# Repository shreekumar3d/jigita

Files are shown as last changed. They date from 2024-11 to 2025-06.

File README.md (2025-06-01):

Jigit

# Jig It !

Ease PCB assembly with 3D printed jigs. Achieve perfectly aligned connectors, with no special motor skills!

JigIt is licensed under the AGPL 3.0 License. If you work with electronics, it can
help you save time, material and money. Should you find value in this tool, the
author implores you to take on the moral obligation of abiding by the
"Equal Opportunity" manifesto. Details of what "equal opportunity" means and your
obligations are in [this page](EQUAL-OPPORTUNITY.md). Please take a moment to read
it before you start using the software.

Starting with a PCB design, JigIt achieves this workflow:

 1. Create a 3D printable jig design from a PCB design.
 2. Print jig.
 3. Mount components and PCB on jig. If you notice tolerance issues, tweak parameters, goto step 1.
 4. Solder away for perfect results... every time !

Jig Usage

Do checkout [this project's hackaday page](https://hackaday.io/project/198409-pcb-assembly-jig-generator)
for stories and updates.

## Demos

There are many ways to use JigIt. Checkout the [demos directory](demos) for details; here are some examples:

[Raspberry Pi Pico/Pico 2](demo/01-rpi-pico-soldering-jig/README.md)

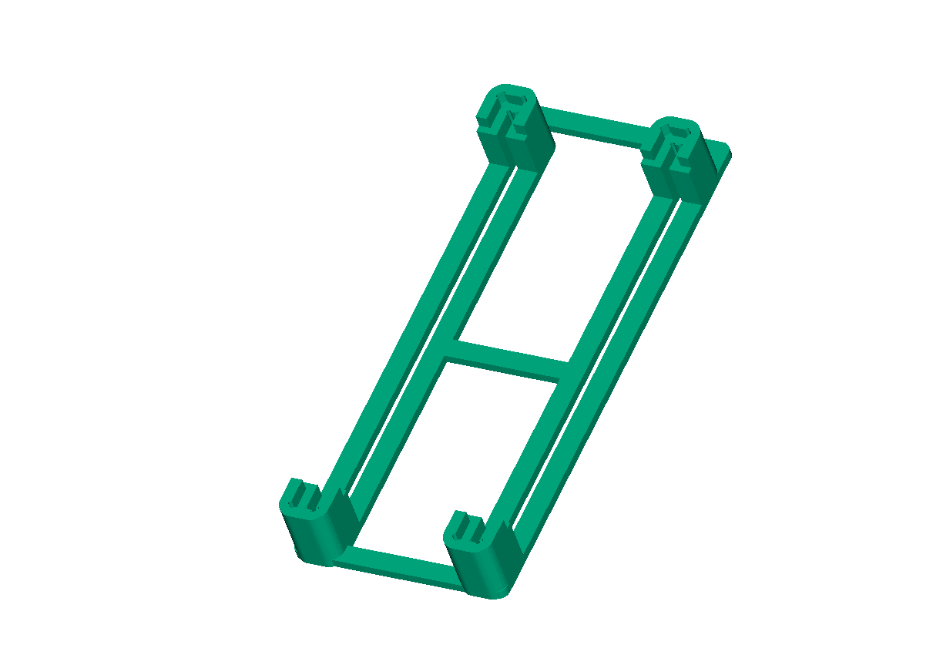
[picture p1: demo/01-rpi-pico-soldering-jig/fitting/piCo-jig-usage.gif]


[Pico Glitcher Board](demo/02-pico-glitcher/README.md)

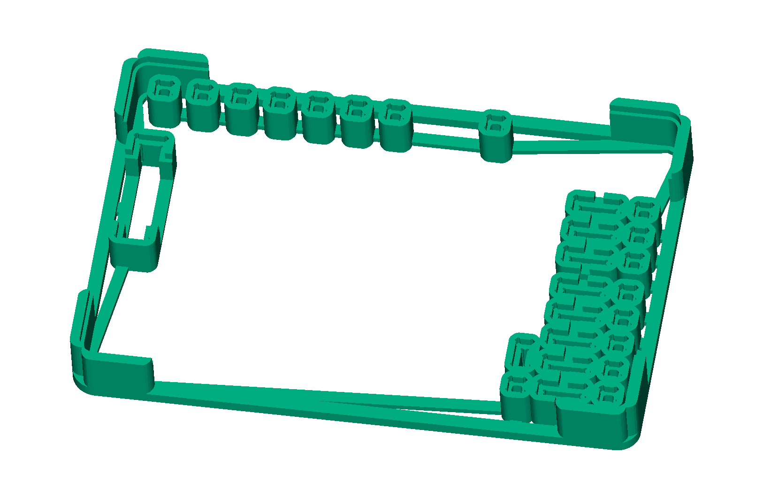
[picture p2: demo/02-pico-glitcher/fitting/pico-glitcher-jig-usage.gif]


JigIt is generic. Have a crazy board like this ProtoConn to solder ?



See [ProtoCon demo](demo/06-lots-of-connectors/README.md) for the details; the jig would look and work like this:

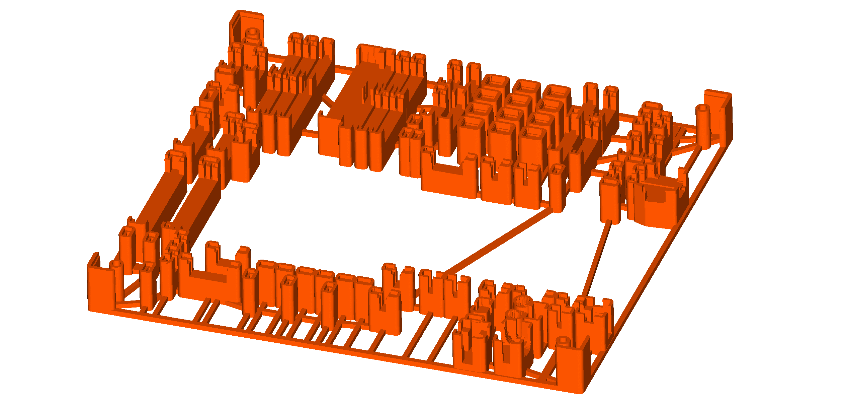
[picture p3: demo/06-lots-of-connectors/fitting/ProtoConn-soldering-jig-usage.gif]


[Gridfinity Containers for Electronics](demo/05-gridfinity/README.md)

It's not just for soldering - make Gridfinity containers for all your electronic components in a snap:

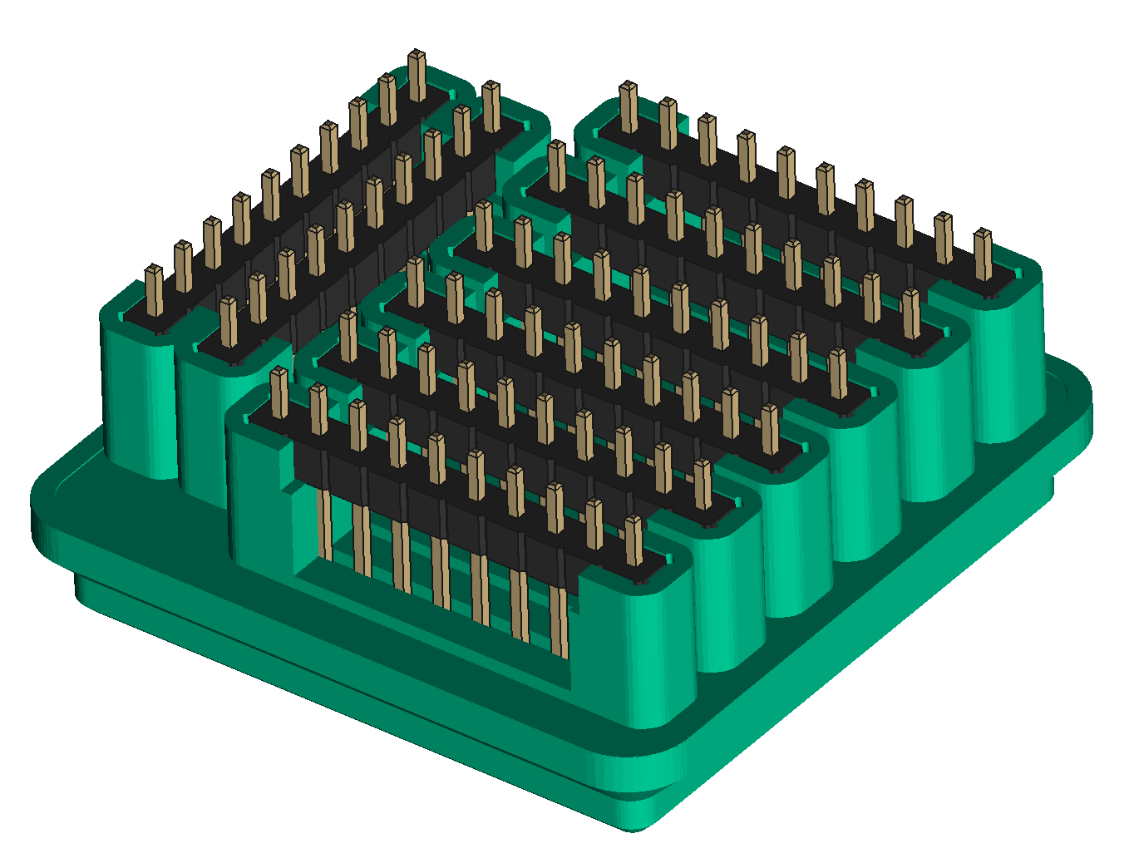
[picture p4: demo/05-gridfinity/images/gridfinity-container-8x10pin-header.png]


It can be used for more than electronics too, with just a bit more work.... Here is an example of a gridfinity container holding three allen keys - M2, M3 and M4:

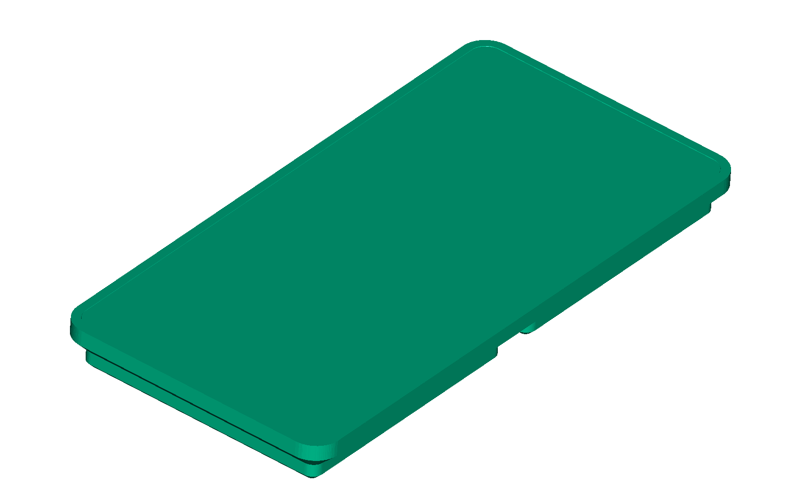
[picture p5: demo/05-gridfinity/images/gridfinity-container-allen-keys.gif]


## Getting Started

See the [Getting Started page](doc/GETTING-STARTED.md).

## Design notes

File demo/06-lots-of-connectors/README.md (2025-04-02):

# ProtoConn

[ProtoConn](https://github.com/Pakequis/ProtoConn) is a prototyping board with
connectors for electronic testing and development. It has an seriously impressive
array of connectors:



Soldering all those components is quite a task.  The large board size of 200x195 mm
calls for some method to hold everything in place.

Here is a soldering jig that solves the problem, created with JigIt:

ProtoConn meets JigIt

This isn't tested yet, but apart from a USB connector that can't be soldered (it's
probably set to SMD) there is a good chance it would work.

To generate the jig, first clone the ProtoConn repository:

    git clone https://github.com/Pakequis/ProtoConn

(tested against commit ffd7c437a8)

The jig was generated using:

    jigit \
      -i ProtoConn/Hardware/ProtoConn.kicad_pcb \
      -c ProtoConn.toml \
      -o jigs/ProtoConn-soldering-jig.3mf

The pre-generated jig is at [jigs/ProtoConn-soldering-jig.3mf](jigs/ProtoConn-soldering-jig.3mf).
You can also take a closer look at the fitting of the jig and the components
by using FreeCAD with this file:
[fitting/ProtoConn-soldering-jig-fitting.FCStd](fitting/ProtoConn-soldering-jig-fitting.FCStd)

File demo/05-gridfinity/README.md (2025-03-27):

# Gridfinity Containers

Jigit can be used to build electronics storage containers for
[Gridfinity](https://gridfinity.xyz/), the popular open source grid storage system.
The cool thing about is that almost the entire workflow happens in your favourite
electronic design software, [KiCAD](https://www.kicad.org/).  KiCAD comes with a
huge library of parts. For components you use, you probably already have your
footprints and symbols defined. With Jigit you can build storage containers for
any of them, in any combination and more.

As an example, here is a gridfinity container that can hold eight 10 pin headers:



Gridfinity works on a grid of 42 mm x 42 mm for the baseplate. A single gridfinity
container is a rounded 41.5 mm square. See the
[specification](https://gridfinity.xyz/specification/) for details.

Jigs generated by jigit may be thought of as a storage container for a set of
electronic components.  The gridfinity container shape can be modelled as a PCB
shape.  The components you need to "store" in the container are placed on the
PCB as desired. Here is one sample layout for a gridfinity container that can
hold ten 1x10 pin standard(2.54mm pitch) headers:

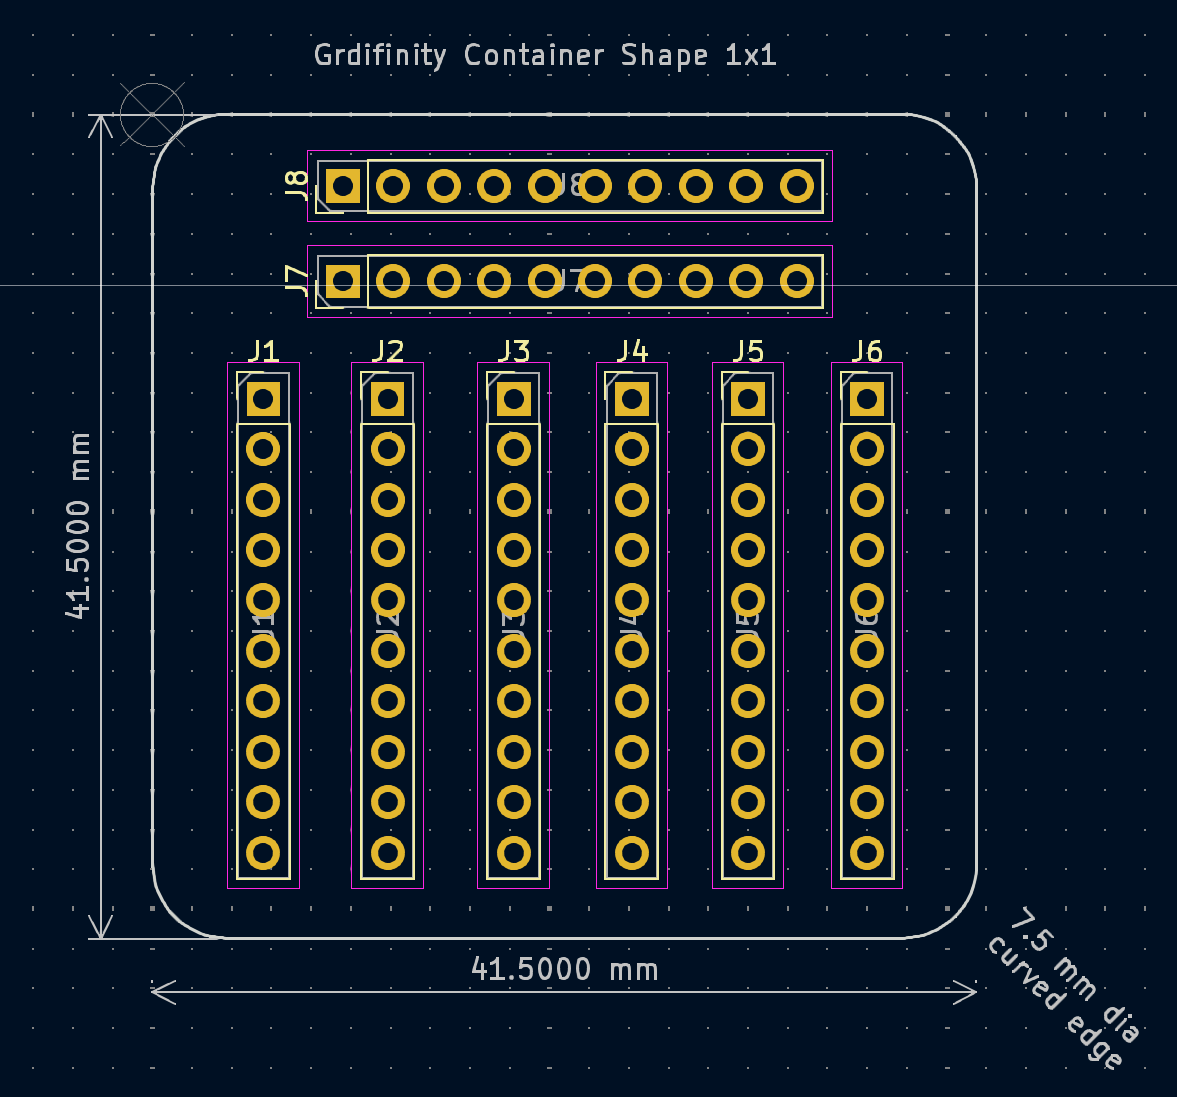
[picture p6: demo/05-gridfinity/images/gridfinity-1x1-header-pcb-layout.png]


Generating the Jig is a simple matter as usual:

    jigit \
      -i gridfinity-1x1/gridfinity-1x1.kicad_pcb \
      -c gridfinity.toml \
      -o jigs/gridfinity-1x1.3mf

Do refer to the settings in the configuration file
[gridfinity.toml](gridfinity.toml).

The resultant jig lacks the gridfinity base.  This needs to be merged in
to create a complete gridfinity container.

[Gridfinity Generator](https://gridfinity.perplexinglabs.com/pr/gridfinity-rebuilt/0/0)
provides a convenient way to generate gridfinity compatible base designs.
Setting height to 1 mm, and disabling the "stackiing lip" provides a convenient
building block with an almost flat top.

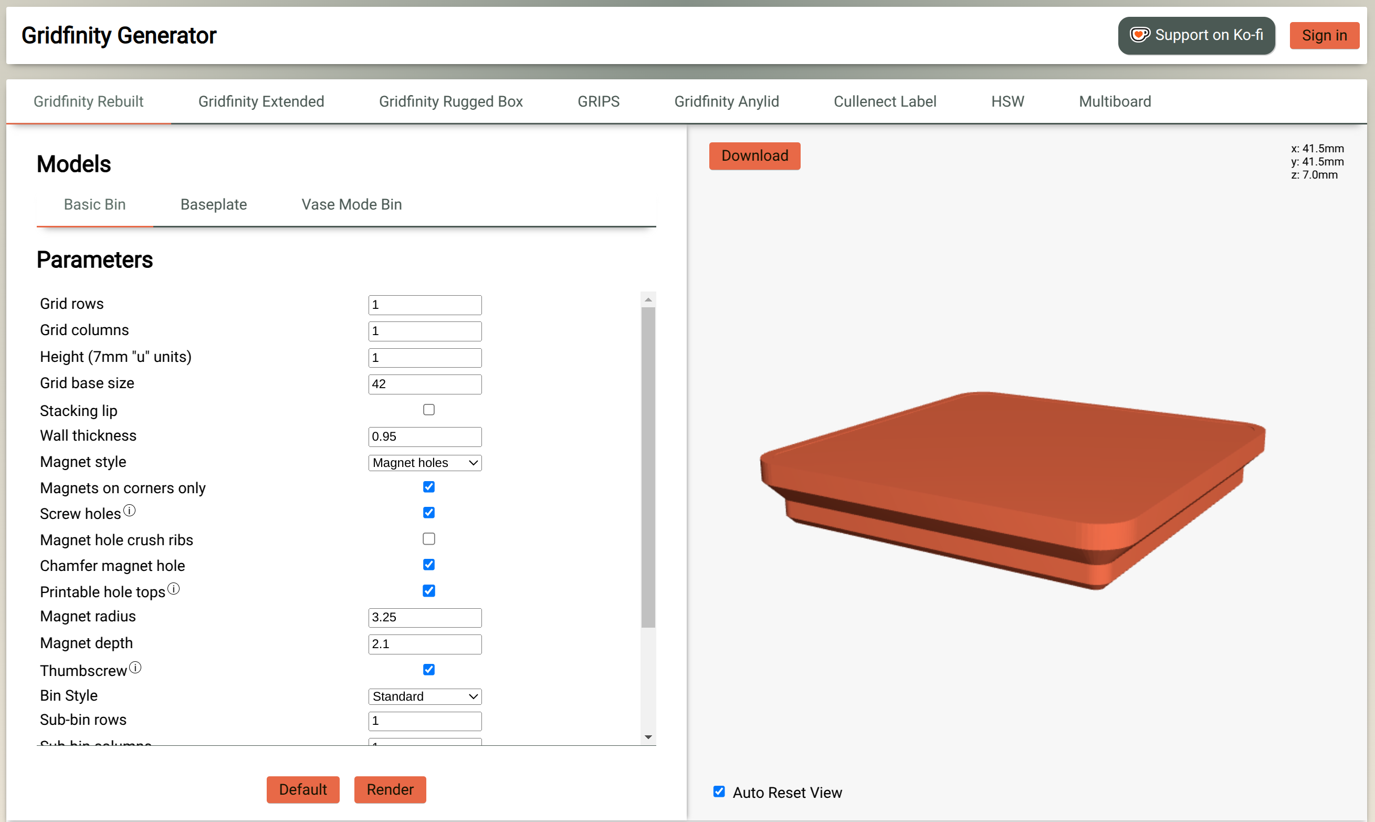
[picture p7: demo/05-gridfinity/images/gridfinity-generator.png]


I have download and saved this file as
[base/base-gridfinity-1x1.stl](base/base-gridfinity-1x1.stl).

To merge the models, let's fire up the slicer (Prusa Slicer in my case).
We'll follow a workflow following the steps in
[this article](https://help.prusa3d.com/article/how-to-lift-object-from-the-print-bed_245192).
First we'll load the base model.  Then we'll right click on the model,
choose "Add Part...", then "Load". Then we'll select the generated jig file.
The jig will get added at unexpected positions. You'll need to match the
position (X, Y) of the jig to the base model. Then change the Z value to
make the generated jig "sit" on the base container. With the right values,
you'll end up with this:

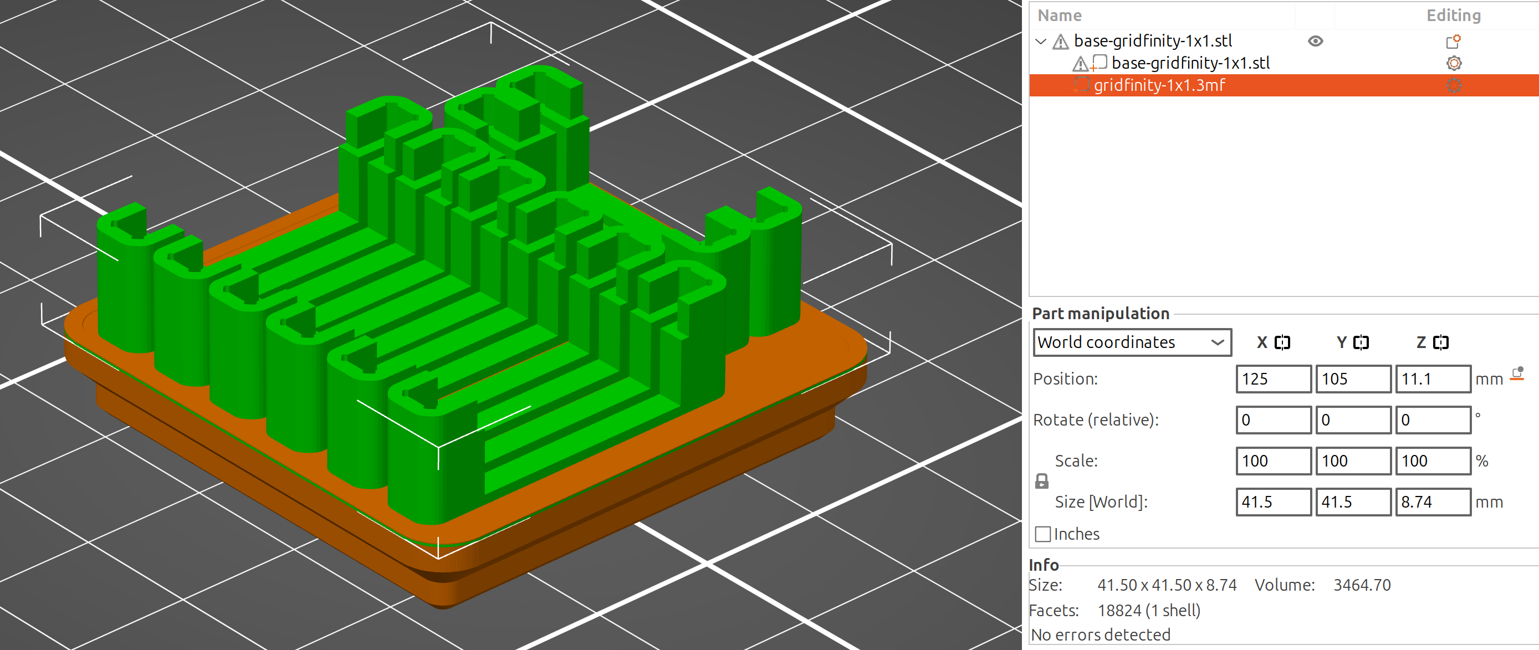
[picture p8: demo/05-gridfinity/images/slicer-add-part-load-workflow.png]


You can now print the resulting file, or save it, say as
[containers/gridfinity-container-8x10pin-header.stl](containers/gridfinity-container-8x10pin-header.stl).
There you have it - gridfinity containers for your own components are just
a few minutes away.

I use FreeCAD with the
[KiCAD StepUp mod](https://www.kicad.org/external-tools/stepup/) workbench for
drawing the PCB outlines to the correct dimension and shape. The container
shapes are in
[gridfinity-container-shapes.FCStd](gridfinity-container-shapes.FCStd)

# Beyond Electronic Components...

KiCAD allows you to load mutiple 3D models into a footprint. These models are
thus not restricted to being electronics components... they can be anything
else too!  After arranging these models in your desired arrangement, you can
then use Jigit to generate generic holders.

Using KiCAD this way is somewhat unusual... but possible! JigIt doesn't have
a UI (yet!) so KiCAD is basically a round-about way to place objects in 3D,
and then have JigIt do its work.

Here is an example of a gridfinity container holding three allen keys -
 M2, M3 and M4:



The relevant files are:

  * KiCAD Design file:
    [allen-keys/allen-keys.kicad_pcb](allen-keys/allen-keys.kicad_pcb)
  * Allen Key 3D models were generated using the Fasteners workbench in FreeCAD,
    and are in [allen-keys/3dmodels](allen-keys/3dmodels)
  * Configuration file to generate jig : [allen-keys.toml](allen-keys.toml)
  * Generated Jig : [jigs/allen-keys.3mf](jigs/allen-keys.3mf)
  * Merged Gridfinity container : [containers/gridfinity-container-allen-keys.stl](containers/gridfinity-container-allen-keys.stl)
  * Gridfinity container base: [base/base-gridfinity-2x1.stl](base/base-gridfinity-2x1.stl)

The workflow is same as earlier, except 3D models of allen keys are assigned
to KiCAD footprints. 3D models also positioned on the same side as the PCB.
If you lookup the design you'll find that they are positioned that the allen
keys are at the same level, despite their differing sizes. Jigit would
ordinarily ignore those; force_mount" is set to true in the config file to
include those.

The jig was generated (as you might expect) using this command:

    jigit \
      -i allen-keys/allen-keys.kicad_pcb \
      -c allen-keys.toml \
      -o jigs/allen-keys.3mf

This feature may be used in many ways. Shipping a kit of components and some
extra hardware ? Use it to add some polish to your kit!

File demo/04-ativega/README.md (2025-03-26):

# AtiVEGA

[AtiVEGA](https://github.com/shreekumar3d/thejas32-testbed) is the board that
lead to the creation of this project.  AtiVEGA is a project to study, understand
and document the THEJAS32 microcontroller.

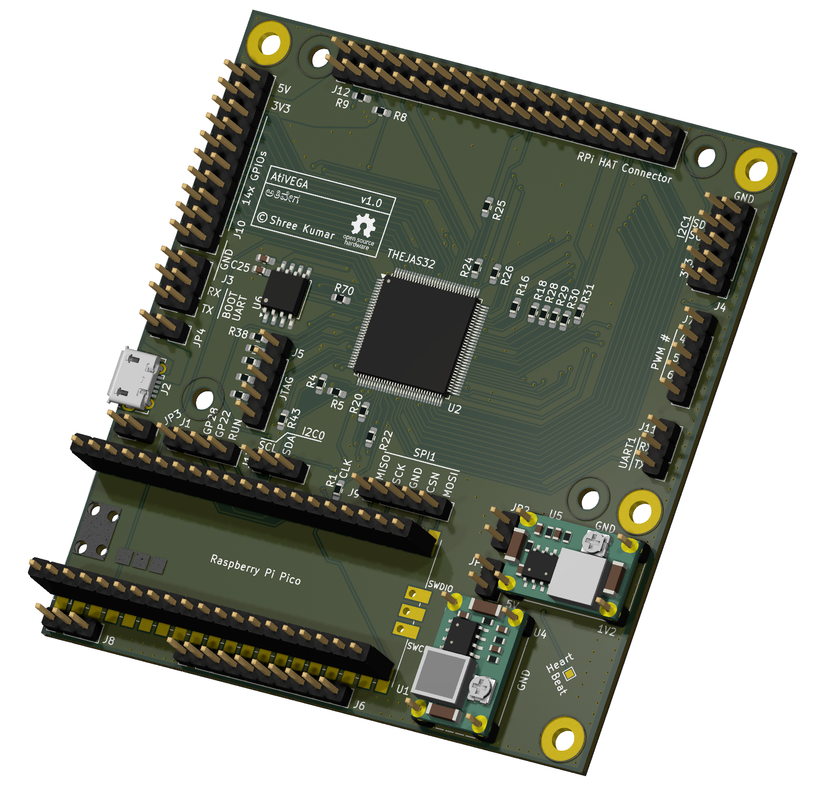
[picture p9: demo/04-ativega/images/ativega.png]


## Story

Many FOSS projects are born out of personal pain points. For Jigita, AtiVEGA
was that pain. Or rather, the pain of soldering the headers on the board.
The board has 26 separate headers:

  * 1 2x20 pin header
  * 1 2x10 pin header
  * 2 1x20 pin sockets
  * 1 1x10 pin header
  * 1 2x5 pin header
  * 1 2x3 pin header
  * 3 1x5 pin headers
  * 1 1x4 pin header
  * 3 1x3 pin headers
  * 4 1x2 pin headers
  * 8 single pin headers!

The single row headers were downright frustrating to solder. I was not happy
with the results as the headers were not perfectly straight most of the times.
Soldering the single pin headers was agony. Not that all that didn't work. It
did. It's just that the effort was too much, and that the results were ugly.

A better method was needed. That's when I decided to build a 3D printed
jig for this. The various shell algorithms evolved with me iteratively testing
jigs with the board. I was always trying to get the fitting right, never once
bothering to solder the board during development. I also realized that this
tool would be generically useful, so I built it as a command line tool with
input from a config file to tweak various things down to a component level.

## Make the Jig!

First, get the design files:

    git clone https://github.com/shreekumar3d/thejas32-testbed

The jig I use now for assembling the board is generated using jigit, using the
following command:

    jigit \
      -i thejas32-testbed/hw/thejas32-testbed.kicad_pcb \
      -c ativega.toml \
      -o jigs/ativega-jig.3mf

The resulting jig [jigs/ativega-jig.3mf](jigs/ativega-jig.3mf) has a shell (holder) for
every component. The PCB can sit in the groove at the four corners. It also has
a provision to insert M3 bolts at the locations of the mounting holes. Additionally,
an M3 bolt may be used near the corner of the PCB that lacks a mounting hole in
the board design.

The workflow with the jig is:

 1. Start with the jig
 2. Insert M3 bolts, lay flat on a table (optional)
 3. Insert headers and USB connector (optional)
 4. Insert the PCB, using the M3 bolts as guides
 5. Hold the PCB in place using M3 nuts (optional)
 6. Check fit and solder!

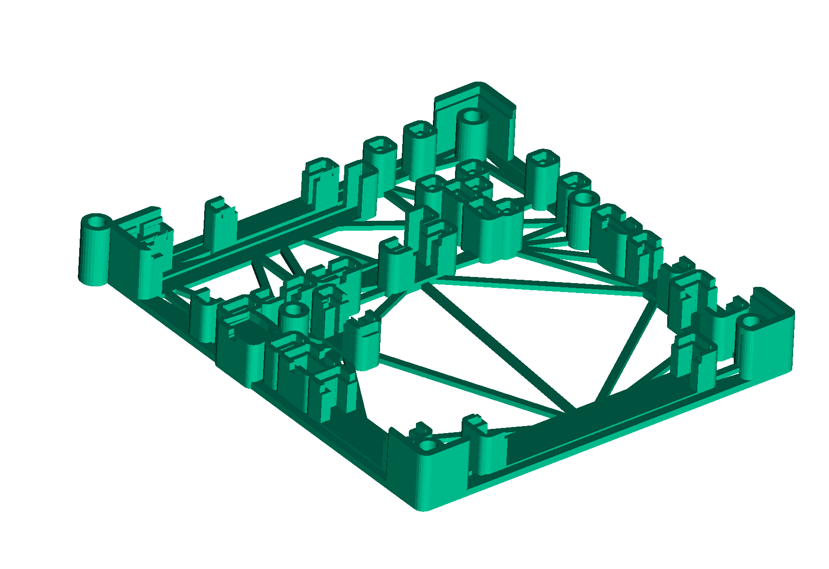
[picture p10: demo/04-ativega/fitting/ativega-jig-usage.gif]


You may check the fitting of these, using FreeCAD by opening this file:
[fitting/ativega-jig-fitting.FCStd](fitting/ativega-jig-fitting.FCStd).

## OpenSCAD Customizer

Changing a configuration file and running the tool to tweak parameters is fine,
but a UI is nicer for tuning. OpenSCAD provides a simple customizer
UI. Jigit has interdependent configuration parameters; not all combinations are
valid. Such things can't be coded into the UI. This makes the customizer less
than ideal, but I figured out I would have to make things work with whatever
limitations it posed. The UI has some extra text which serves as warnings, but
that's pretty much it.

Generating the openscad file is a simple matter of changing the filename
extension of the output:

    jigit \
      -i thejas32-testbed/hw/thejas32-testbed.kicad_pcb \
      -c ativega.toml \
      -o jigs/ativega-jig.scad

Now you may open [jigs/ativega-jig.scad](jigs/ativega-jig.scad) using OpenSCAD. For
**_fast_** mesh generation performance, use a development version and turn on the
usage of Manifold (under Preferences > Advanced > 3D Rendering > Backend).

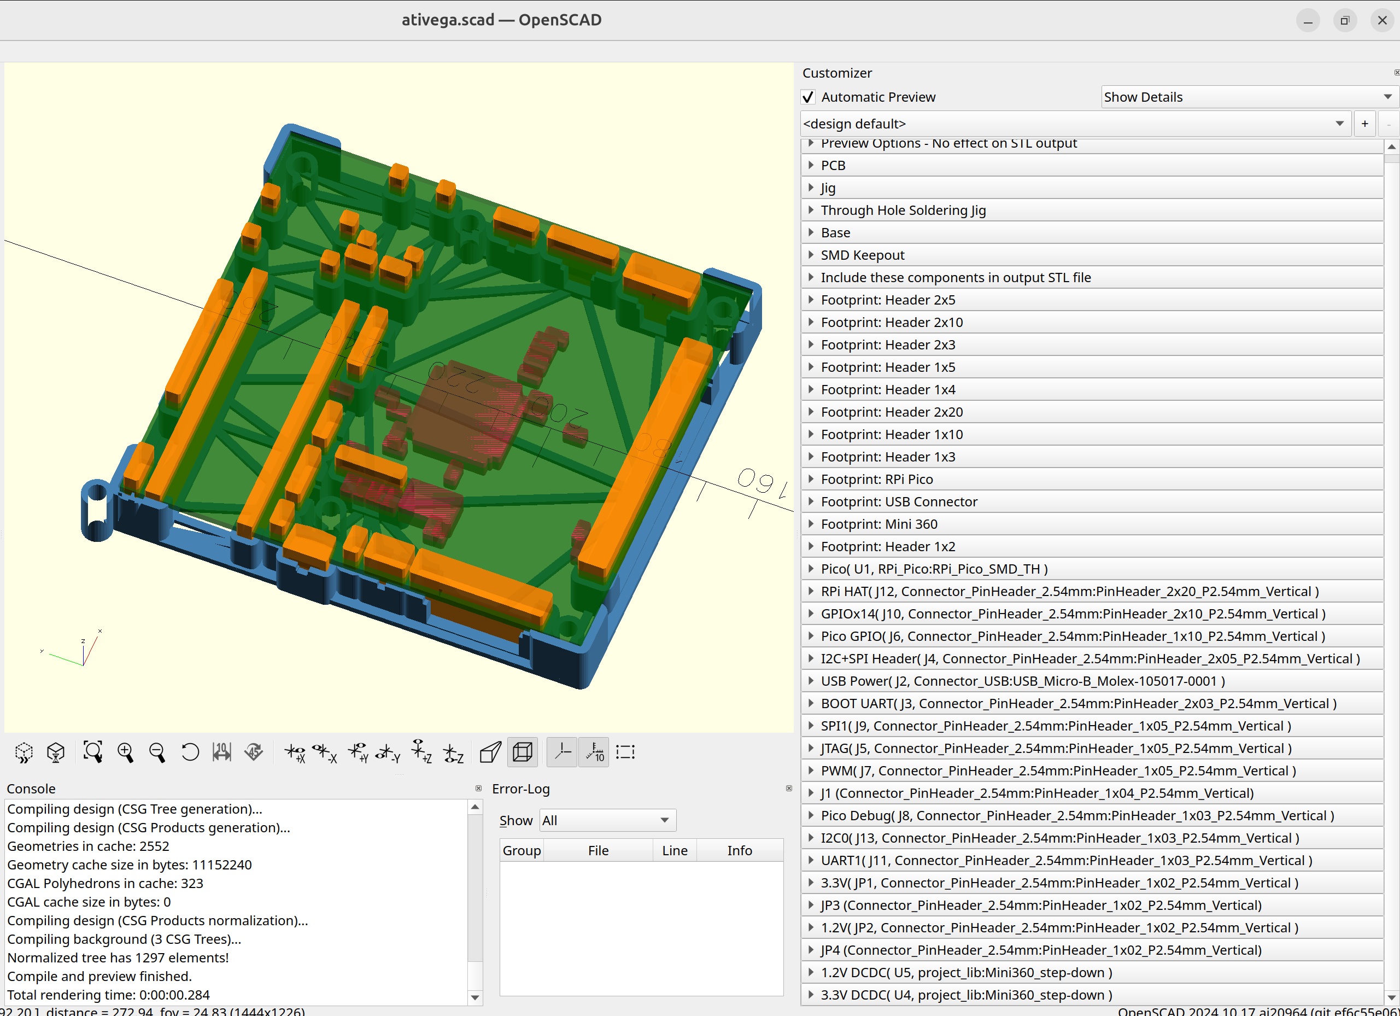
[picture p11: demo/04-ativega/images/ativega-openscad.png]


The panel on the right has helpful labels identifying components.

# Advanced Usage

## Two part jig

Jigit can create a "two part" jig as well. This makes even more of the internal
structure visible, and may take less time/material, depending on the mode
(not the case for AtiVEGA):

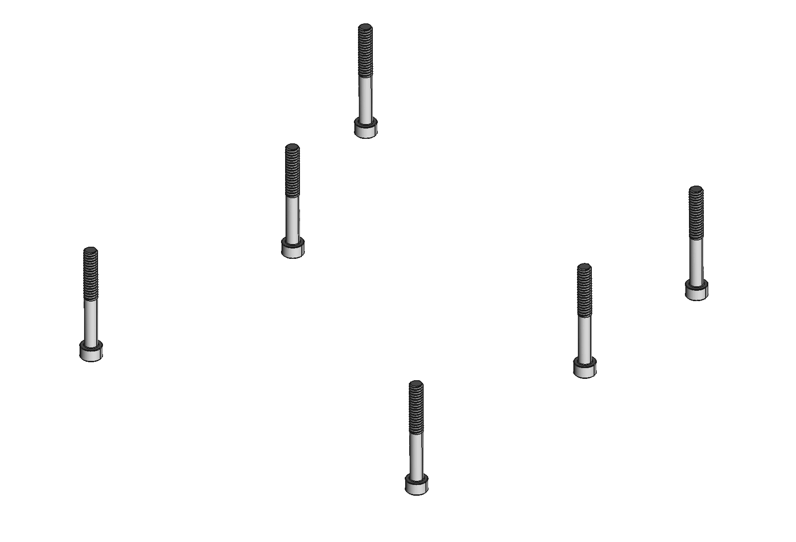
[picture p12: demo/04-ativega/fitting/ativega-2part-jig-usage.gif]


This is generated by using the following command with jigit:

    jigit \
      -i thejas32-testbed/hw/thejas32-testbed.kicad_pcb \
      -c ativega-2part-jig.toml \
      -o jigs/ativega-2part-jig.3mf

The resulting jig [jigs/ativega-2part-jig.3mf](jigs/ativega-2part-jig.3mf) has two
parts separated by a small gap.  This gap isn't visible easily.  However, you can
use an option in your slicer to split this into two parts. In Prusa Slicer, this
option is called "split to objects". After that, choose "arrange objects".
Once done, the model will look as below, in the slicer:

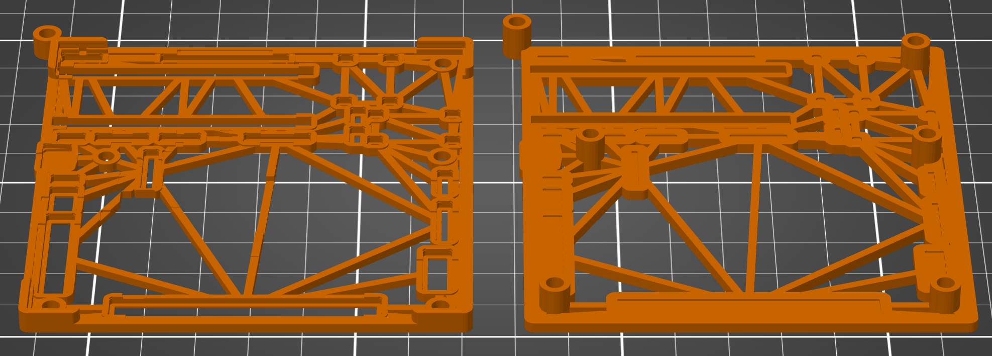
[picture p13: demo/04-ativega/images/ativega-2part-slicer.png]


The model can now be printed.

The 2 part jig may feel somewhat flimsy compared to a single part jig.  This may
come in useful for projects that have taller jigs. It also sparks ideas about
other ways of building jigs - e.g. using laser cut thin acrylic or steel sheets,
or even cardboard.

The 2 part jig should be considered experimental. Tou should ideally cross-check
the generated jig in the slicer prior to printing.

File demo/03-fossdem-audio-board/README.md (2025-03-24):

# FOSSDEM Audio Board

This illustrative example showcases jigit handling components of various heights.

[FOSSDEM](https://fosdem.org/2025/) conference uses a
[dedicated "videobox"](https://blog.brixit.nl/after-fosdem-videobox-updates/)
to record and live-stream their videos. Their "box" has various internal boards,
including a
[digital audio mixer board](https://blog.brixit.nl/digital-audio-mixer-pt-2/).

The audio board has a few XLR audio connectors (two different types of connectors),
a berg header, and a couple of audio jacks. The board looks roughly like this in
3D:

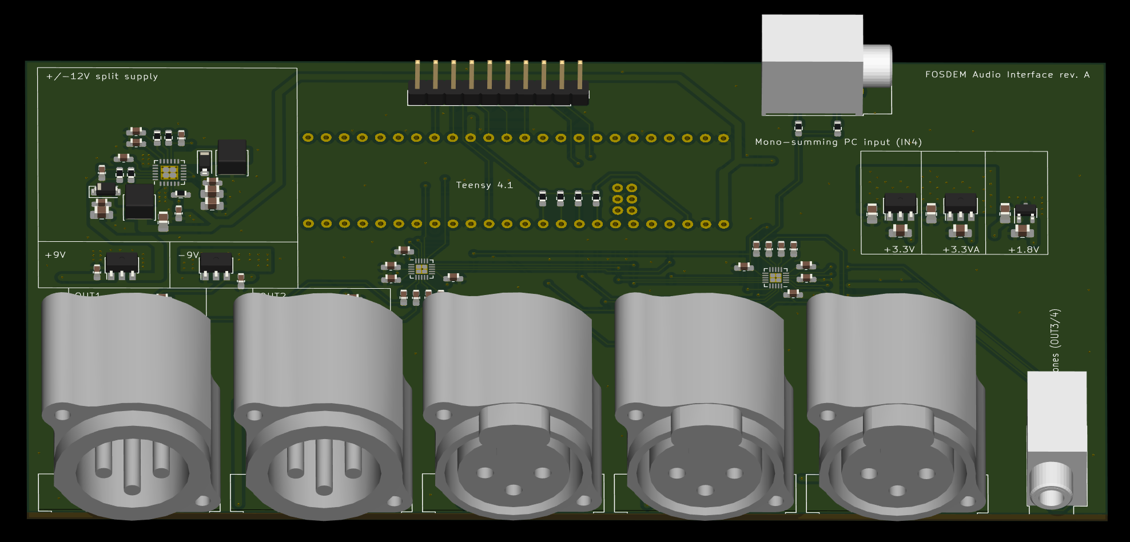
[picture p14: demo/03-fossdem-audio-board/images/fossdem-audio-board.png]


Jigit can be used to create a soldering jig for this board. We first need to get
the design files:

    git clone https://git.sr.ht/~martijnbraam/mixolydian-4x4

(tested with git commit a2705c04)

Next, use the following command:

    jigit \
      -i mixolydian-4x4/mixolydian-4x4.kicad_pcb \
      -c mixolydian-4x4.toml \
      -o jigs/mixolydian-4x4-soldering-jig.3mf

Here's how the generated jig [mixolydian-4x4-soldering-jig.3mf](jigs/mixolydian-4x4-soldering-jig.3mf)
looks and works:

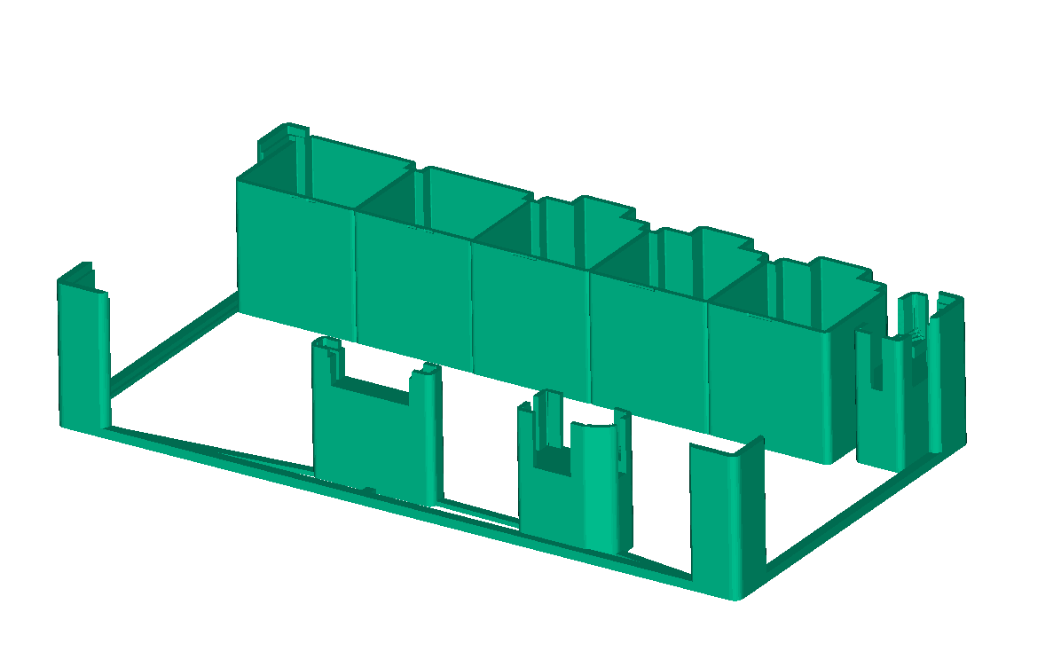
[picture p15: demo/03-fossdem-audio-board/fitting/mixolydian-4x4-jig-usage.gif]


The jig sits on a groove at the board edges. The PCB sits on it. Note that
different types of holding structures are generated for the two different types
of XLR connectors. Also note that the holding structures are connected to the
main structure, ensuring a printable single piece model.

The board also uses a Teensy 4.1. However, the 3D models for the teensy footprint
are not included in the PCB design. Thus, jigit doesn't generate structures to hold
the berg header used to mount the Teensy. Same is the case of the ethernet breakout
pins of the Teensy.

The jig generated jig here hasn't been tested with a real board. It should work,
though. You may also verify the fitting by opening this file in FreeCAD:
[fitting/mixolydian-4x4-jig-fitting.FCStd](fitting/mixolydian-4x4-jig-fitting.FCStd)

This is a medium size PCB - 152 mm x 80 mm. The jig would take an estimated 43 grams of
material, and print in 4 hrs 30 min at 0.2mm layer height in my printer (Prusa i3
MK2 with 0.4 mm nozzle).

A common way of creating soldering jigs involves manually creating cavities inside
a solid. With a change of options, Jigit can generate such jigs as well..! E.g.

    jigit \
      -i mixolydian-4x4/mixolydian-4x4.kicad_pcb \
      -c mixolydian-4x4-solid.toml \
      -o jigs/mixolydian-4x4-soldering-jig-solid.3mf

That gives us [mixolydian-4x4-soldering-jig-solid.3mf](jigs/mixolydian-4x4-soldering-jig-solid.3mf),
which looks like this:

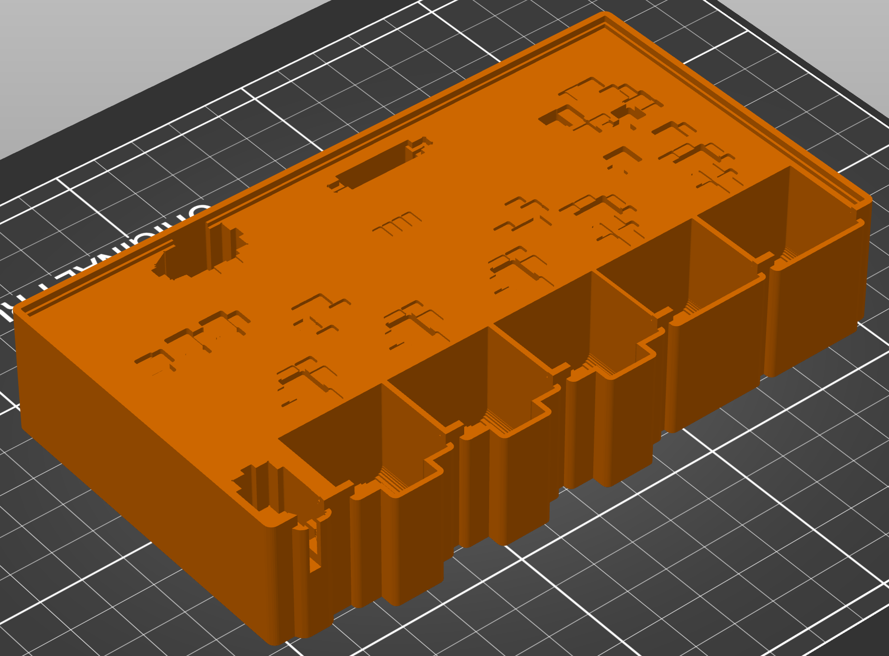
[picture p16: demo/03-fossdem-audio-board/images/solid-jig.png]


This model has cavities for SMD components with ample clearance.  A partially
assembled board (e.g. with SMD components) can thus be used with this jig.

Printing this model even with 5% infill would need 80 grams of material (2x) and
6 hrs+ on my printer with 0.2mm layer height. We save close to 50% on time and
material by generating component holders where needed.

Finally, sparse holders makes it easy to examine and verify (and if necessary tune)
the fit.

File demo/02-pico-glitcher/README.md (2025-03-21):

# Pico Glitcher

[fault-injection-library](https://github.com/MKesenheimer/fault-injection-library)
is an interesting project. It provides a python library to perform fault injection
attacks on microcontrollers.  Also includes PicoGlitcher - hardware based on a RPi
Pico for fault injection. [PicoGlitcher v1](https://www.tindie.com/products/faulty-hardware/picoglitcher-v1-pcb-only/)
and [PicoGlitcher v2](https://www.tindie.com/products/faulty-hardware/picoglitcher-v2/)
are both available.

The v1 variant has many headers and a 2 SMA connectors. This board caught my eye as
a good community board to test with. I was able to generate a jig for this. (The
project has some jigs to assist soldering too, likely designed manually)

First, get the design files:

    git clone https://github.com/MKesenheimer/fault-injection-library.git

(tested with git commit 0122cd1d)

Next, generate the jig using jigit:

    jigit \
      -i fault-injection-library/schematics/kicad/pico-glitcher-v1/pico-glitcher-v1.1.kicad_pcb \
      -c pico-glitcher.toml \
      -o jigs/pico-glitcher-jig.3mf

If you print this jig, this is how your workflow would look. Keep the jig on a table,
insert the headers into their slots (single pin headers included), pop in the PCB,
and solder away!



Note that the SMA connectors are missing in the jig. The footprints in
the design files do not refer to the 3D models for these connectors. Due to this,
jigit cannot compute the holders for those.

The settings in [pico-glitcher.toml](pico-glitcher.toml) generates a sparse jig
to save material and print time. A thin jig makes it possible to easily locate
fitment issues - plastic will flex something isn't sitting well. The jig also
supports the PCB at the edges.

Perfection of component fitting can be verified from the sides. You may also
check the fitment by opening this file
[fitting/pico-glitcher-v1.1-with-jig.FCStd](fitting/pico-glitcher-v1.1-with-jig.FCStd)
in FreeCAD.

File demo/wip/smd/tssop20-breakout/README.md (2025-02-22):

# TSSOP20 Breakout Board

The breakout board is this [part](https://sharvielectronics.com/product/soic-to-dip-20-pin-adapter/).
This provides a breakout from TSSOP20 (0.65 mm pitch) to dual 0.1 inch berg headers.

This is an off the shelf TSSOP20 breakout board. The design of this isn't
available, so I am forced to create it from scratch by reverse engineering
from the actual board. Only then can I make it work solderless.

Here's how I do the "reverse engineering":

* Scan the breakout board using a regular color scanner (part of all in one printer). Scan at 300 DPI. Board is kept in a corner next to a small helper object (also 3D
printed - see scan-helper.3mf, dimensions in freecad file). Helper provides margin
and ensures corners of the PCB don't get chewed by the scanner.
* Import scanned image to inkscape.
* Mark PCB with a rectangle size same as PCB size
* Overlay circles of 2mm size to correspond to mounting holes
* Find approx corner of TSSOP footprint, mark with a rectangle
* Create a KiCAD file and transfer all the coordinates from the inkscape file to
kicad file. See tssop20-breakout schematic and PCB file.

Verified the board by printing the layout from KiCAD.  Print front copper layer
and edge cuts layer, and exported to PDF file (see tssop20-breakout.pdf). I next
printed this 1:1 on an A4 paper sheet and checked location of holes. Seemed
perfect!

## Testing

Ran

  $ ./jigit -i demo/tssop20-breakout/tssop20-breakout.kicad_pcb -o tssop20-breakout.stl

Printed the STL file. The M2 hole locations seem perfect, and the 10 pin header
location too.  The TSSOP location seems fine to the eye, but further checks are
required to be sure.

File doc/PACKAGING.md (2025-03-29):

# Windows

Jigit can be packaged as a single file executable, with all dependencies.

Single EXE eliminates the need for having a local installation of KiCAD
to use the tool.  While the resultant binary is large (~200 MB), it may be
used directly.

## Setup dependencies

First, install KiCAD 8.0 for your own user (not for "everyone") - this installs
inside user directory. This has the internal python interpreter that we'll 
use for packaging.

Next, install the dependent packages using "python -m pip". Take care to use
the Python from the KiCAD installation directory. E.g., for if your user name
is "admin", you would use

    C:\Users\admin\AppData\Local\Programs\KiCad\8.0\bin\python -m pip install <package_name>

You can roughly use the following sequence to install the dependencies:

    pip install appdirs
    pip install pyclipr
    pip install toml
    pip install trimesh[easy]
    pip install rectpack
    pip install python_tsp
    pip install SolidPython2
    pip install -U pyinstaller

## Redistributable EXE

pyinstaller can now create a single file redistributable EXE in one step:

    \path\to\KiCad\8.0\bin\scripts\pyinstaller jigit --onefile --collect-all=pymeshlab --collect-all=numpy

The output dist\jigit.exe file can be copied to any windows system.

Users will need external dependencies (OpenSCAD, FreeCAD) to use Jigit.

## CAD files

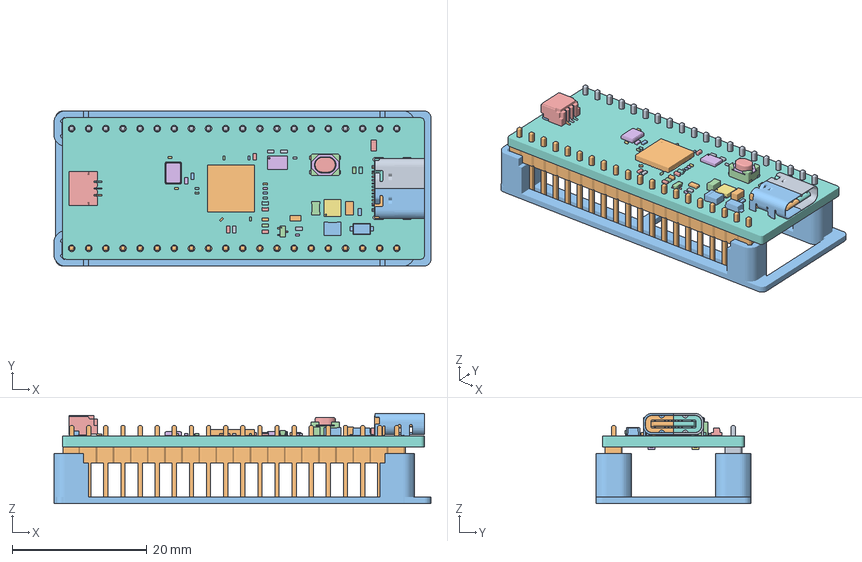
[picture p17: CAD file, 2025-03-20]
demo/01-rpi-pico-soldering-jig/fitting/project-piCo-with-soldering-jig.FCStd
55.9 x 23.0 x 13.4 mm
R_0402_1005Metric
C_0805_2012Metric
L_1008_2520Metric
R_0402_1005Metric002
W25X40CLUXIG TR
W25X40CLUXIG TR001
W25X40CLUXIG TR002
W25X40CLUXIG TR003
W25X40CLUXIG TR004
W25X40CLUXIG TR005
W25X40CLUXIG TR006
W25X40CLUXIG TR007
W25X40CLUXIG TR008
W25X40CLUXIG TR009
W25X40CLUXIG TR010
C_0201_0603Metric
R_0402_1005Metric004
C_0402_1005Metric
R_0402_1005Metric006
PTS810SJS250SMTR LFS
PTS810SJS250SMTR LFS001
PTS810SJS250SMTR LFS002
PTS810SJS250SMTR LFS003
PTS810SJS250SMTR LFS004
PTS810SJS250SMTR LFS005
PTS810SJS250SMTR LFS006
2DA1774Q-7-F
2DA1774Q-7-F001
2DA1774Q-7-F002
2DA1774Q-7-F003
2DA1774Q-7-F004
R_0201_0603Metric
R_0402_1005Metric008
C_0201_0603Metric002
C_0201_0603Metric004
C_0201_0603Metric006
C_0402_1005Metric002
R_0402_1005Metric010
C_0201_0603Metric008
R_0402_1005Metric012
R_0402_1005Metric014
R_0603_1608Metric
R_0402_1005Metric016
R_0402_1005Metric018
C_0402_1005Metric004
C_0201_0603Metric010
C_0201_0603Metric012
USB_C_Receptacle_16P_TopMnt_Horizontal_GCT_USB4105-xx-A
USB_C_Receptacle_16P_TopMnt_Horizontal_GCT_USB4105-xx-A001
USB_C_Receptacle_16P_TopMnt_Horizontal_GCT_USB4105-xx-A002
USB_C_Receptacle_16P_TopMnt_Horizontal_GCT_USB4105-xx-A003
USB_C_Receptacle_16P_TopMnt_Horizontal_GCT_USB4105-xx-A004
USB_C_Receptacle_16P_TopMnt_Horizontal_GCT_USB4105-xx-A005
USB_C_Receptacle_16P_TopMnt_Horizontal_GCT_USB4105-xx-A006
USB_C_Receptacle_16P_TopMnt_Horizontal_GCT_USB4105-xx-A007
USB_C_Receptacle_16P_TopMnt_Horizontal_GCT_USB4105-xx-A008
USB_C_Receptacle_16P_TopMnt_Horizontal_GCT_USB4105-xx-A009
USB_C_Receptacle_16P_TopMnt_Horizontal_GCT_USB4105-xx-A010
USB_C_Receptacle_16P_TopMnt_Horizontal_GCT_USB4105-xx-A011
USB_C_Receptacle_16P_TopMnt_Horizontal_GCT_USB4105-xx-A012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

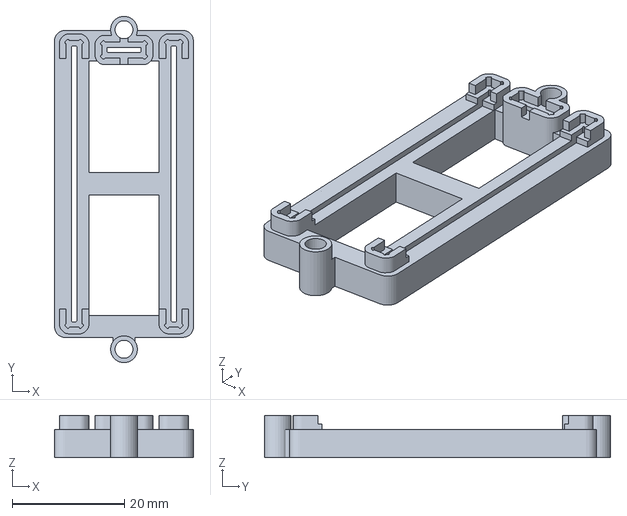
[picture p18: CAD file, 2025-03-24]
demo/01-rpi-pico-soldering-jig/jigs/pico-all-soldering-jig-simple.3mf
24.8 x 61.8 x 7.54 mm

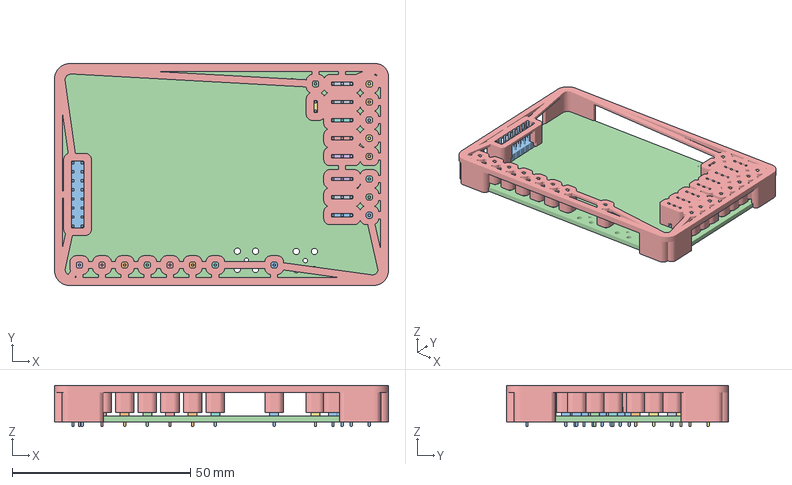
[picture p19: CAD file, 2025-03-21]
demo/02-pico-glitcher/fitting/pico-glitcher-v1.1-with-jig.FCStd
93.6 x 62.2 x 11.5 mm
PinHeader_1x03_P254mm_Vertical008
PinHeader_1x01_P254mm_Vertical017
PinHeader_1x01_P254mm_Vertical018
PinHeader_1x01_P254mm_Vertical019
PinHeader_1x01_P254mm_Vertical020
PinHeader_1x03_P254mm_Vertical009
PinHeader_1x01_P254mm_Vertical021
PinHeader_1x01_P254mm_Vertical022
PinHeader_1x01_P254mm_Vertical023
PinHeader_1x01_P254mm_Vertical024
PinHeader_2x08_P254mm_Vertical001
PinHeader_1x01_P254mm_Vertical025
PinHeader_1x01_P254mm_Vertical026
PinHeader_1x03_P254mm_Vertical010
PinHeader_1x02_P254mm_Vertical001
PinHeader_1x01_P254mm_Vertical027
PinHeader_1x03_P254mm_Vertical011
PinHeader_1x01_P254mm_Vertical028
PinHeader_1x03_P254mm_Vertical012
PinHeader_1x01_P254mm_Vertical029
PinHeader_1x03_P254mm_Vertical013
PinHeader_1x01_P254mm_Vertical030
PinHeader_1x01_P254mm_Vertical031
PinHeader_1x03_P254mm_Vertical014
PinHeader_1x03_P254mm_Vertical015
PinHeader_1x01_P254mm_Vertical032
PinHeader_1x01_P254mm_Vertical033
_autosave-pico-glitcher-v1.1_PCB
pico-glitcher-jig

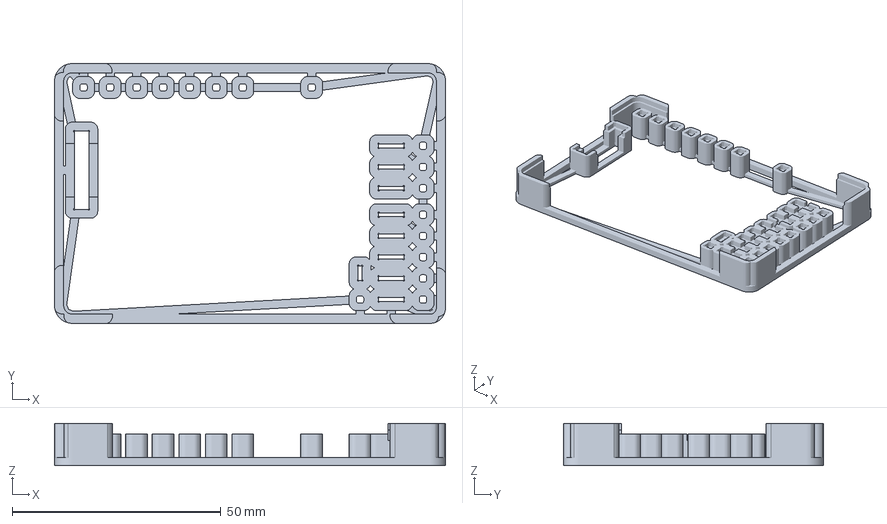
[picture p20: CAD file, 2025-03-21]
demo/02-pico-glitcher/jigs/pico-glitcher-jig.3mf
93.6 x 62.2 x 10.1 mm

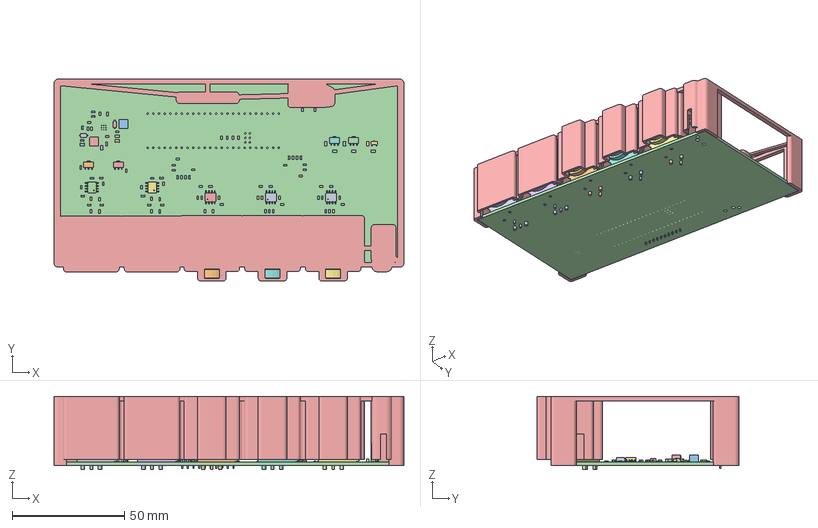
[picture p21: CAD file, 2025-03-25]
demo/03-fossdem-audio-board/fitting/mixolydian-4x4-jig-fitting.FCStd
155.8 x 89.9 x 32.7 mm
C_0805_2012Metric
C_0603_1608Metric
C_0603_1608Metric002
C_0603_1608Metric004
C_0603_1608Metric006
R_0603_1608Metric
R_0603_1608Metric002
C_0603_1608Metric008
C_0603_1608Metric010
R_0603_1608Metric004
R_0603_1608Metric006
R_0603_1608Metric008
CQ assembly
CQ assembly001
CQ assembly002
CQ assembly003
CQ assembly004
C_0603_1608Metric012
CQ assembly006
CQ assembly007
CQ assembly008
R_0603_1608Metric010
SOT-23-3
C_0603_1608Metric014
C_0603_1608Metric016
R_0603_1608Metric012
R_0603_1608Metric014
C_0603_1608Metric018
R_0603_1608Metric016
R_0603_1608Metric018
R_0603_1608Metric020
C_0603_1608Metric020
R_0603_1608Metric022
C_0603_1608Metric022
R_0603_1608Metric024
C_0805_2012Metric002
C_0603_1608Metric024
R_0603_1608Metric026
C_0805_2012Metric004
C_0603_1608Metric026
R_0603_1608Metric028
R_0603_1608Metric030
C_0805_2012Metric006
C_0603_1608Metric028
R_0603_1608Metric032
R_0603_1608Metric034
C_0603_1608Metric030
C_0603_1608Metric032
D_SOD_123
C_0603_1608Metric034
C_0603_1608Metric036
C_0603_1608Metric038
R_0603_1608Metric036
R_0603_1608Metric038
R_0603_1608Metric040
C_0805_2012Metric008
R_0603_1608Metric042
C_0603_1608Metric040
R_0603_1608Metric044
C_0805_2012Metric010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

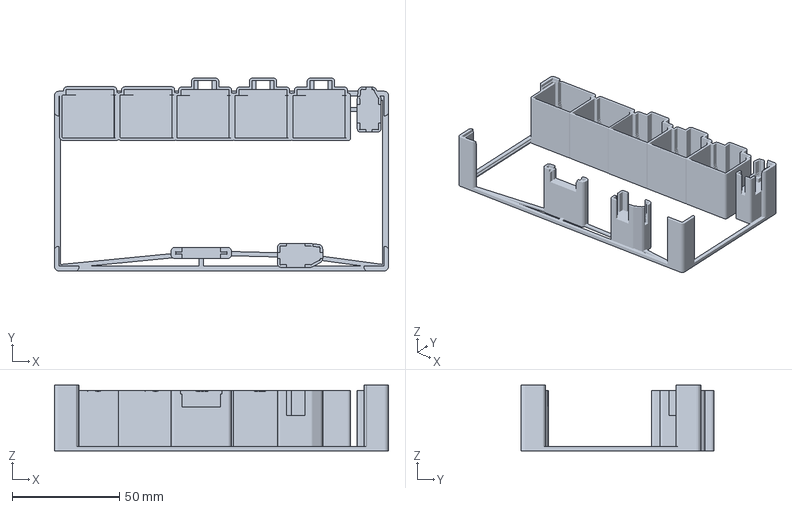
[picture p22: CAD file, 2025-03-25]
demo/03-fossdem-audio-board/jigs/mixolydian-4x4-soldering-jig.3mf
155.8 x 89.9 x 30.8 mm

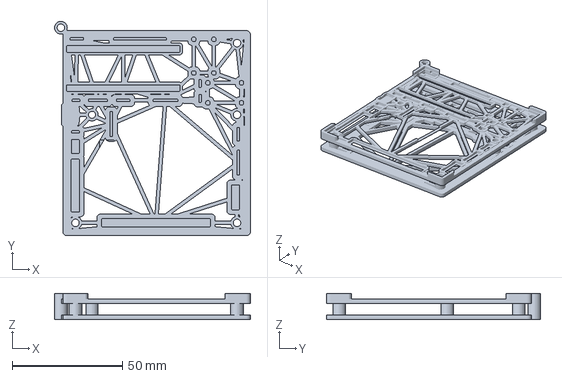
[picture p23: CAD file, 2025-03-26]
demo/04-ativega/jigs/ativega-2part-jig.3mf
88.9 x 97.2 x 11.9 mm

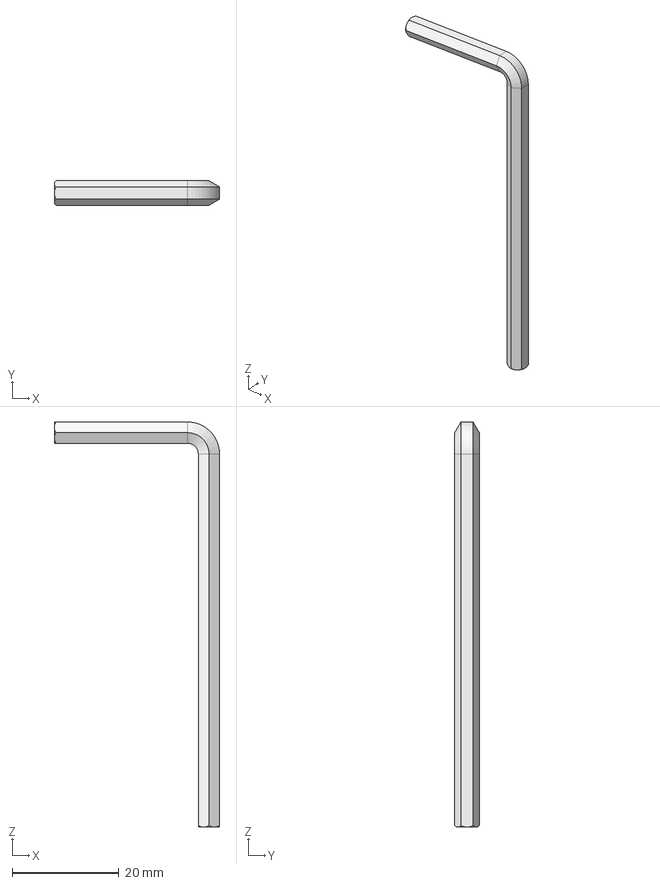
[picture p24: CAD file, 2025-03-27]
demo/05-gridfinity/allen-keys/3dmodels/4-HexKey.step
31.0 x 4.62 x 76.0 mm

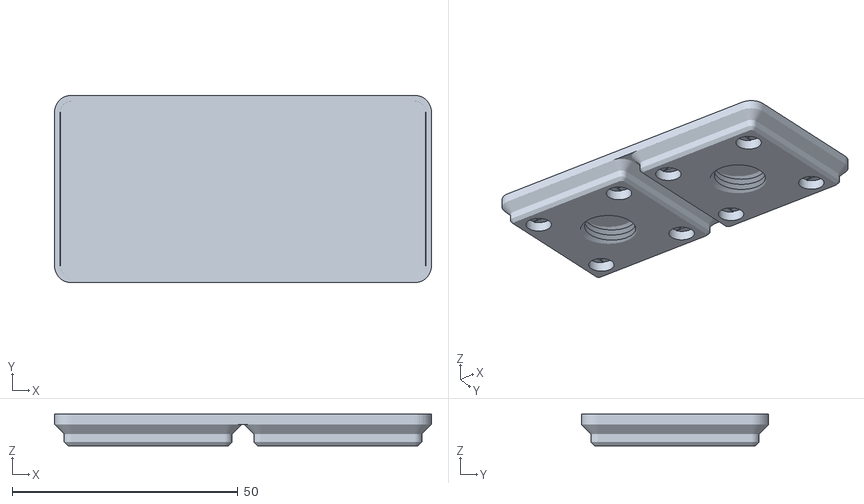
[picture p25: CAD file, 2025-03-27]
demo/05-gridfinity/base/base-gridfinity-2x1.stl
83.5 x 41.5 x 7.00

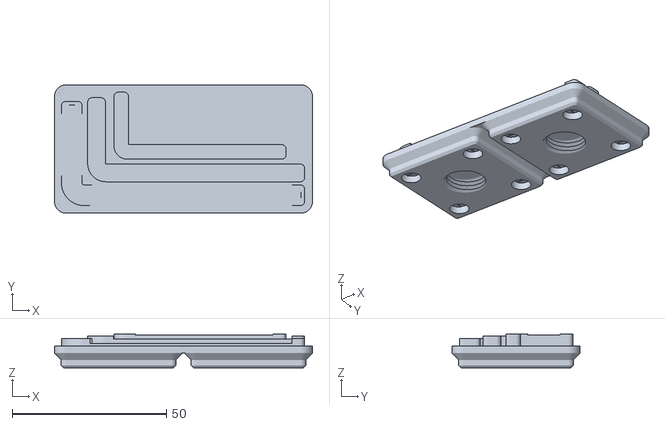
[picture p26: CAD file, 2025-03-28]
demo/05-gridfinity/containers/gridfinity-container-allen-keys.stl
83.5 x 41.5 x 10.9

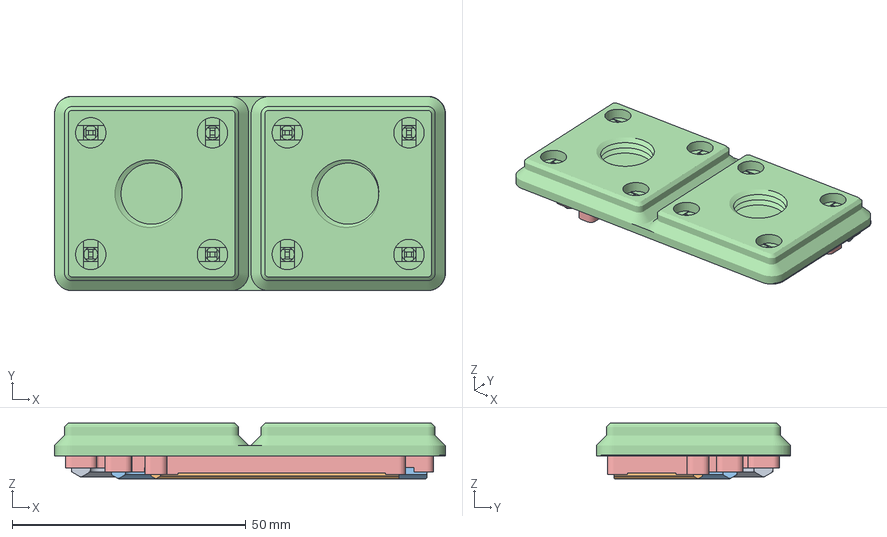
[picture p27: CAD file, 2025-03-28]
demo/05-gridfinity/fitting/allen-key.FCStd
83.5 x 41.5 x 11.9 mm
4-HexKey
2-HexKey
3-HexKey
base-gridfinity-2x1
allen-keys-holder

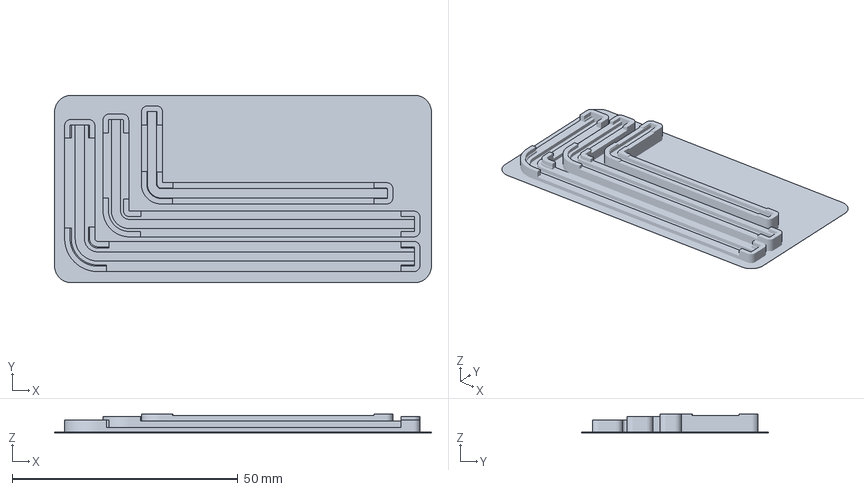
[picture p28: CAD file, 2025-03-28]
demo/05-gridfinity/jigs/allen-keys.3mf
83.5 x 41.5 x 4.16 mm

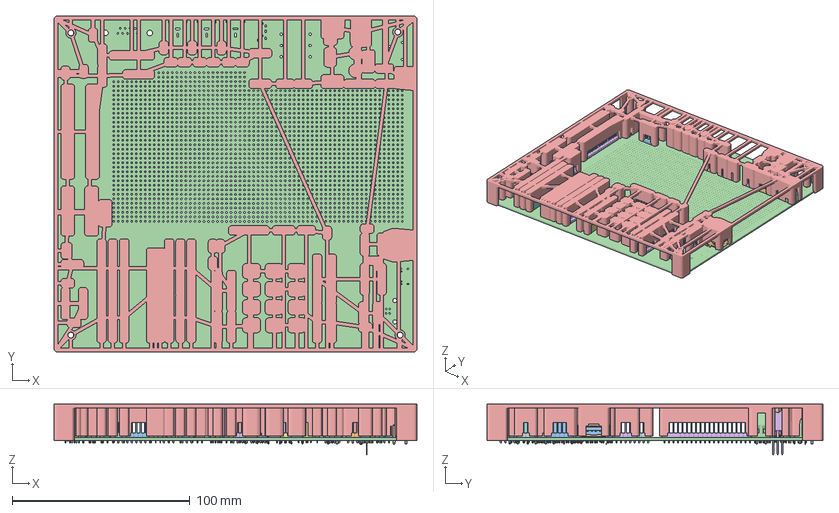
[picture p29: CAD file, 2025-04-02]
demo/06-lots-of-connectors/fitting/ProtoConn-soldering-jig-fitting.FCStd
204.5 x 189.2 x 28.7 mm
SW_PUSH_6mm
PinSocket_1x20_P2.54mm_Vertical
PinHeader_1x02_P254mm_Vertical
PinHeader_1x02_P254mm_Vertical001
PinHeader_1x02_P254mm_Vertical002
PinHeader_1x08_P254mm_Vertical
PinHeader_1x02_P254mm_Vertical003
PinSocket_1x12_P2.54mm_Vertical
PinHeader_1x09_P254mm_Vertical
PinHeader_1x02_P254mm_Vertical004
SW_PUSH_6mm002
PinHeader_1x02_P254mm_Vertical005
CP_Radial_D50mm_P250mm
PinHeader_2x04_P254mm_Vertical
PinHeader_1x04_P254mm_Vertical
PinHeader_1x10_P254mm_Vertical
SW_PUSH_6mm004
PinHeader_1x02_P254mm_Vertical006
PinHeader_1x02_P254mm_Vertical007
BarrelJack_Horizontal
BarrelJack_Horizontal001
BarrelJack_Horizontal002
BarrelJack_Horizontal003
BarrelJack_Horizontal004
PinSocket_1x03_P2.54mm_Vertical
PinHeader_1x02_P254mm_Vertical008
PinSocket_1x08_P2.54mm_Vertical
TerminalBlock_Phoenix_MKDS_15_2_1x02_P500mm_Horizontal
PinHeader_1x04_P254mm_Vertical001
PinHeader_2x05_P254mm_Vertical
PinHeader_1x08_P254mm_Vertical001
TerminalBlock_Phoenix_MKDS_15_2_1x02_P500mm_Horizontal001
PinHeader_2x05_P127mm_Vertical
PinHeader_1x06_P254mm_Vertical
PinHeader_1x06_P254mm_Vertical001
PinHeader_1x12_P254mm_Vertical
PinHeader_1x04_P254mm_Vertical002
PinSocket_1x03_P2.54mm_Vertical002
PinSocket_1x03_P2.54mm_Vertical004
PinSocket_1x10_P2.54mm_Vertical
PinHeader_1x10_P254mm_Vertical001
USB_A_Molex_67643_Horizontal
USB_A_Molex_67643_Horizontal001
USB_A_Molex_67643_Horizontal002
USB_A_Molex_67643_Horizontal003
USB_A_Molex_67643_Horizontal004
USB_A_Molex_67643_Horizontal005
USB_A_Molex_67643_Horizontal006
USB_A_Molex_67643_Horizontal007
USB_A_Molex_67643_Horizontal008
USB_A_Molex_67643_Horizontal009
PinHeader_1x06_P254mm_Vertical002
SW_PUSH_6mm006
SW_PUSH_6mm008
PinHeader_1x12_P254mm_Vertical001
PinHeader_1x02_P254mm_Vertical009
PinHeader_1x02_P254mm_Vertical010
PinHeader_1x02_P254mm_Vertical011
PinHeader_1x04_P254mm_Vertical003
SW_PUSH_6mm010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

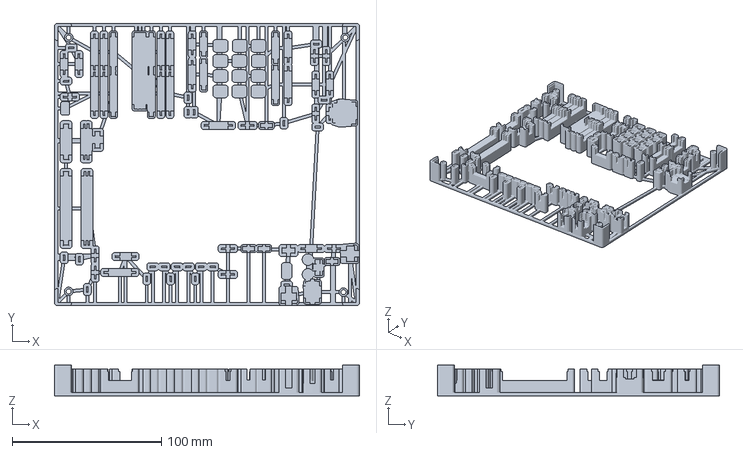
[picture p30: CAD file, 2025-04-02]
demo/06-lots-of-connectors/jigs/ProtoConn-soldering-jig.3mf
204.5 x 189.2 x 20.6 mm

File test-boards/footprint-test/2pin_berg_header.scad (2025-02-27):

// Customizable Jig Generator
// In OpenSCAD, use "Description Only" for best user experience
// understanding the tunable parameters.
// -----------------------------------------------------
// Auto generated file by jigit, the awesome automatic
// jig generator for your PCB designs. Checkout the project
// at https://github.com/shreekumar3d/jigit
// -----------------------------------------------------
// Configuration file : test-boards/footprint-test/config.toml
//
// Complete configuration file is embedded at the end of this
// file.
//Thickness(height) of base
Base_Thickness = 0.4; // [0.0:0.2:1.0]
/* [Include these footprints in output STL file] */
//Connector_PinHeader_2.54mm:PinHeader_1x02_P2.54mm_Vertical
Include_FP1_in_Jig=true; // [false,true]
/* [Footprint: Connector_PinHeader_2.54mm:PinHeader_1x02_P2.54mm_Vertical] */
//XY Gap in shell for component insertion
Effective_Shell_Gap_For_FP1 = 0.1;
//Thickness of shell
Effective_Shell_Thickness_For_FP1 = 1.2;
//Z distance from start of shell to PCB
Effective_Shell_Clearance_From_PCB_For_FP1 = 1;
//Type of shell for this footprint
Shell_Type_For_FP1="fitting"; // [wiggle,fitting,fitting_flower,tight,courtyard]
//Insert this component into jig from this side.(Bottom insertion requires wiggle or courtyard shell to work)
Insert_FP1_From="top"; // [top,bottom]
//Wrapper thickness
Wrapper_Thickness_For_FP1=0.0; // [0:0.1:10.0]
//Wrapper height
Wrapper_Height_For_FP1=0.0; // [0:0.1:8.539479970932007]
/* [Hidden] */

// Height of the tallest component on the top side
topmost_z=8.539479970932007;
    bottom_insertion_z = 9.339479970932008;
// Height of the individual components
max_z_FP1= (Insert_FP1_From=="bottom")? bottom_insertion_z : 8.539479970932007; //Applies to 3D Model(s): ${KICAD8_3DMODEL_DIR}/Connector_PinHeader_2.54mm.3dshapes/PinHeader_1x02_P2.54mm_Vertical.wrl
min_z_FP1= -2.9997399854660034;
// } END : Computed Values

tiny_dimension = 0.0001;
PCB_Thickness = 0;
c_Base_Thickness = Base_Thickness;
c_Base_Line_Height = 1.0;
module peri_line_scad(start,end,line_width){
	hull() {
		translate(v = start) {
			circle(d = line_width);
		}
		translate(v = end) {
			circle(d = line_width);
		}
	}
}
module fitting_cuts_FP1_0(){
	union() {
		translate(v = [0, 0, ((PCB_Thickness - tiny_dimension) + max(2.54, Effective_Shell_Clearance_From_PCB_For_FP1))]) {
			rotate(a = [0, 0, 0]) {
				linear_extrude(height = ((min(((topmost_z + c_Base_Thickness) - c_Base_Line_Height), 8.539479970932007) - max(2.54, Effective_Shell_Clearance_From_PCB_For_FP1)) + (2 * tiny_dimension))) {
					union() {
						peri_line_scad([0.3193328983662705, -2.8593330119131193],[0.46075425460358, -3.000754368150429],0.4);
						peri_line_scad([0.3193328983662705, 0.3193328983662705],[0.46075425460358, 0.46075425460358],0.4);
						peri_line_scad([-0.3193328983662705, 0.3193328983662705],[-0.46075425460358, 0.46075425460358],0.4);
						peri_line_scad([-0.3193328983662705, -2.8593330119131193],[-0.46075425460358, -3.000754368150429],0.4);
					}
				}
			}
		}
		translate(v = [0, 0, (PCB_Thickness - tiny_dimension)]) {
			rotate(a = [0, 0, 0]) {
				linear_extrude(height = (min(((topmost_z + c_Base_Thickness) - c_Base_Line_Height), 8.539479970932007) + (2 * tiny_dimension))) {
					union();
				}
			}
		}
		translate(v = [0, 0, ((PCB_Thickness - tiny_dimension) + max(-2.9997399854660034, Effective_Shell_Clearance_From_PCB_For_FP1))]) {
			rotate(a = [0, 0, 0]) {
				linear_extrude(height = ((min(((topmost_z + c_Base_Thickness) - c_Base_Line_Height), 2.54) - max(-2.9997399854660034, Effective_Shell_Clearance_From_PCB_For_FP1)) + (2 * tiny_dimension))) {
					union() {
						peri_line_scad([1.2690761204389767, -3.55561725607815],[1.4538520326436606, -3.632153928784291],0.4);
						hull() {
							union() {
								peri_line_scad([1.2690761204674887, 1.0156173317072148],[1.4538520269697461, 1.0921540181802327],0.4);
								peri_line_scad([1.0156173317072148, 1.2690761204674887],[1.0921540181802327, 1.4538520269697461],0.4);
							}
						}
						peri_line_scad([1.0156173317072148, 1.2690761204674887],[1.0921540181802327, 1.4538520269697461],0.4);
						hull() {
							union() {
								peri_line_scad([-1.0156173317072148, 1.2690761204674887],[-1.0921540181802327, 1.4538520269697461],0.4);
								peri_line_scad([-1.2690761204674887, 1.0156173317072148],[-1.4538520269697461, 1.0921540181802327],0.4);
							}
						}
						peri_line_scad([-1.2690761204674887, 1.0156173317072148],[-1.4538520269697461, 1.0921540181802327],0.4);
						hull() {
							union() {
								peri_line_scad([-1.2690761204389767, -3.55561725607815],[-1.4538520326436606, -3.632153928784291],0.4);
								peri_line_scad([-1.0156173316383803, -3.809076120496001],[-1.0921540318782748, -3.993852021295831],0.4);
							}
						}
						peri_line_scad([-1.0156173316383803, -3.809076120496001],[-1.0921540318782748, -3.993852021295831],0.4);
						hull() {
							union() {
								peri_line_scad([1.0156173316383803, -3.809076120496001],[1.0921540318782748, -3.993852021295831],0.4);
								peri_line_scad([1.2690761204389767, -3.55561725607815],[1.4538520326436606, -3.632153928784291],0.4);
							}
						}
					}
				}
			}
		}
		translate(v = [0, 0, (PCB_Thickness - tiny_dimension)]) {
			rotate(a = [0, 0, 0]) {
				linear_extrude(height = (min(((topmost_z + c_Base_Thickness) - c_Base_Line_Height), 2.54) + (2 * tiny_dimension))) {
					union();
				}
			}
		}
	}
}
module hullpoly_FP1_0_0(){
	polygon(points = [[1.27, -3.555999939441681], [1.27, 1.0160000151395798], [1.0160000151395798, 1.27], [-1.0160000151395798, 1.27], [-1.27, 1.0160000151395798], [-1.27, -3.555999939441681], [-1.0160000151395798, -3.81], [1.0160000151395798, -3.81]]);
}
module hullpoly_FP1_0_1(){
	polygon(points = [[0.32004000514745706, -2.8600401186943056], [0.32004000514745706, 0.32004000514745706], [-0.32004000514745706, 0.32004000514745706], [-0.32004000514745706, -2.8600401186943056]]);
}
module fitting_pocket_FP1_0(){
	union() {
		translate(v = [0, 0, ((PCB_Thickness - tiny_dimension) + -2.9997399854660034)]) {
			rotate(a = [0, 0, 0]) {
				linear_extrude(height = (5.539739985466003 + (2 * tiny_dimension))) {
					offset(r = Effective_Shell_Gap_For_FP1) {
						union() {
							hullpoly_FP1_0_0();
						}
					}
				}
			}
		}
		translate(v = [0, 0, ((PCB_Thickness - tiny_dimension) + 2.54)]) {
			rotate(a = [0, 0, 0]) {
				linear_extrude(height = (5.999479970932007 + (2 * tiny_dimension))) {
					offset(r = Effective_Shell_Gap_For_FP1) {
						union() {
							hullpoly_FP1_0_1();
						}
					}
				}
			}
		}
	}
}
module ref_FP1_0(){
	union() {
		hullpoly_FP1_0_0();
	}
}
module wiggle_pocket_FP1_0(){
	translate(v = [0, 0, (PCB_Thickness + min_z_FP1)]) {
		rotate(a = [0, 0, 0]) {
			linear_extrude(height = (max_z_FP1 - min_z_FP1)) {
				offset(r = Effective_Shell_Gap_For_FP1) {
					union() {
						ref_FP1_0();
					}
				}
			}
		}
	}
}
module perimeter_FP1_0(){
	union() {
		translate(v = [0, 0, (PCB_Thickness + Effective_Shell_Clearance_From_PCB_For_FP1)]) {
			rotate(a = [0, 0, 0]) {
				linear_extrude(height = ((topmost_z - Effective_Shell_Clearance_From_PCB_For_FP1) + c_Base_Thickness)) {
					offset(r = (Effective_Shell_Gap_For_FP1 + Effective_Shell_Thickness_For_FP1)) {
						union() {
							ref_FP1_0();
						}
					}
				}
			}
		}
		translate(v = [0, 0, (((PCB_Thickness + topmost_z) + c_Base_Thickness) - Wrapper_Height_For_FP1)]) {
			rotate(a = [0, 0, 0]) {
				linear_extrude(height = Wrapper_Height_For_FP1) {
					difference() {
						offset(r = ((Effective_Shell_Gap_For_FP1 + Effective_Shell_Thickness_For_FP1) + Wrapper_Thickness_For_FP1)) {
							union() {
								ref_FP1_0();
							}
						}
						offset(r = (Effective_Shell_Gap_For_FP1 + Effective_Shell_Thickness_For_FP1)) {
							union() {
								ref_FP1_0();
							}
						}
					}
				}
			}
		}
	}
}
module fitting_flower_FP1_0(){
	union() {
		translate(v = [0, 0, ((PCB_Thickness + max(-2.9997399854660034, Effective_Shell_Clearance_From_PCB_For_FP1)) - tiny_dimension)]) {
			rotate(a = [0, 0, 0]) {
				linear_extrude(height = ((max_z_FP1 - max(-2.9997399854660034, Effective_Shell_Clearance_From_PCB_For_FP1)) + (2 * tiny_dimension))) {
					difference() {
						offset(r = (Effective_Shell_Gap_For_FP1 + Effective_Shell_Thickness_For_FP1)) {
							union() {
								hullpoly_FP1_0_0();
							}
						}
						offset(r = Effective_Shell_Gap_For_FP1) {
							union() {
								hullpoly_FP1_0_0();
							}
						}
					}
				}
			}
		}
		translate(v = [0, 0, ((PCB_Thickness + max(2.54, Effective_Shell_Clearance_From_PCB_For_FP1)) - tiny_dimension)]) {
			rotate(a = [0, 0, 0]) {
				linear_extrude(height = ((max_z_FP1 - max(2.54, Effective_Shell_Clearance_From_PCB_For_FP1)) + (2 * tiny_dimension))) {
					difference() {
						offset(r = (Effective_Shell_Gap_For_FP1 + Effective_Shell_Thickness_For_FP1)) {
							union() {
								hullpoly_FP1_0_1();
							}
						}
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

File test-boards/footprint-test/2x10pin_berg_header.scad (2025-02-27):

// Customizable Jig Generator
// In OpenSCAD, use "Description Only" for best user experience
// understanding the tunable parameters.
// -----------------------------------------------------
// Auto generated file by jigit, the awesome automatic
// jig generator for your PCB designs. Checkout the project
// at https://github.com/shreekumar3d/jigit
// -----------------------------------------------------
// Configuration file : config.toml
//
// Complete configuration file is embedded at the end of this
// file.
//Thickness(height) of base
Base_Thickness = 0.4; // [0.0:0.2:1.0]
/* [Include these footprints in output STL file] */
//Connector_PinHeader_2.54mm:PinHeader_1x10_P2.54mm_Vertical
Include_FP1_0_in_Jig=true; // [false,true]
//Connector_PinHeader_2.54mm:PinHeader_1x10_P2.54mm_Vertical
Include_FP1_1_in_Jig=true; // [false,true]
/* [Footprint: Connector_PinHeader_2.54mm:PinHeader_1x10_P2.54mm_Vertical] */
//XY Gap in shell for component insertion
Effective_Shell_Gap_For_FP1_0 = 0.1;
//Thickness of shell
Effective_Shell_Thickness_For_FP1_0 = 1.2;
//Z distance from start of shell to PCB
Effective_Shell_Clearance_From_PCB_For_FP1_0 = 1;
//Type of shell for this footprint
Shell_Type_For_FP1_0="fitting"; // [wiggle,fitting,fitting_flower,tight,courtyard]
//Insert this component into jig from this side.(Bottom insertion requires wiggle or courtyard shell to work)
Insert_FP1_0_From="top"; // [top,bottom]
//Wrapper thickness
Wrapper_Thickness_For_FP1_0=0.0; // [0:0.1:10.0]
//Wrapper height
Wrapper_Height_For_FP1_0=0.0; // [0:0.1:8.539479970932007]
/* [Footprint: Connector_PinHeader_2.54mm:PinHeader_1x10_P2.54mm_Vertical] */
//XY Gap in shell for component insertion
Effective_Shell_Gap_For_FP1_1 = 0.1;
//Thickness of shell
Effective_Shell_Thickness_For_FP1_1 = 1.2;
//Z distance from start of shell to PCB
Effective_Shell_Clearance_From_PCB_For_FP1_1 = 1;
//Type of shell for this footprint
Shell_Type_For_FP1_1="fitting"; // [wiggle,fitting,fitting_flower,tight,courtyard]
//Insert this component into jig from this side.(Bottom insertion requires wiggle or courtyard shell to work)
Insert_FP1_1_From="top"; // [top,bottom]
//Wrapper thickness
Wrapper_Thickness_For_FP1_1=0.0; // [0:0.1:10.0]
//Wrapper height
Wrapper_Height_For_FP1_1=0.0; // [0:0.1:8.539479970932007]
/* [Hidden] */

// Height of the tallest component on the top side
topmost_z=8.539479970932007;
    bottom_insertion_z = 9.339479970932008;
// Height of the individual components
max_z_FP1_0= (Insert_FP1_0_From=="bottom")? bottom_insertion_z : 8.539479970932007; //Applies to 3D Model(s): ${KICAD8_3DMODEL_DIR}/Connector_PinHeader_2.54mm.3dshapes/PinHeader_1x10_P2.54mm_Vertical.wrl
min_z_FP1_0= -2.9997399854660034;
max_z_FP1_1= (Insert_FP1_1_From=="bottom")? bottom_insertion_z : 8.539479970932007; //Applies to 3D Model(s): ${KICAD8_3DMODEL_DIR}/Connector_PinHeader_2.54mm.3dshapes/PinHeader_1x10_P2.54mm_Vertical.wrl
min_z_FP1_1= -2.9997399854660034;
// } END : Computed Values

tiny_dimension = 0.0001;
PCB_Thickness = 0;
c_Base_Thickness = Base_Thickness;
c_Base_Line_Height = 1.0;
module peri_line_scad(start,end,line_width){
	hull() {
		translate(v = start) {
			circle(d = line_width);
		}
		translate(v = end) {
			circle(d = line_width);
		}
	}
}
module fitting_cuts_FP1_0_0(){
	union() {
		translate(v = [0, 0, ((PCB_Thickness - tiny_dimension) + max(2.54, Effective_Shell_Clearance_From_PCB_For_FP1_0))]) {
			rotate(a = [0, 0, 0]) {
				linear_extrude(height = ((min(((topmost_z + c_Base_Thickness) - c_Base_Line_Height), 8.539479970932007) - max(2.54, Effective_Shell_Clearance_From_PCB_For_FP1_0)) + (2 * tiny_dimension))) {
					union() {
						peri_line_scad([0.3193328983662705, 0.3193328983662705],[0.46075425460358, 0.46075425460358],0.4);
						peri_line_scad([-0.3193328983662705, 0.3193328983662705],[-0.46075425460358, 0.46075425460358],0.4);
						peri_line_scad([-0.3193328983662705, -23.179333920287906],[-0.46075425460358, -23.320755276525215],0.4);
						peri_line_scad([0.3193328983662705, -23.179333920287906],[0.46075425460358, -23.320755276525215],0.4);
					}
				}
			}
		}
		translate(v = [0, 0, (PCB_Thickness - tiny_dimension)]) {
			rotate(a = [0, 0, 0]) {
				linear_extrude(height = (min(((topmost_z + c_Base_Thickness) - c_Base_Line_Height), 8.539479970932007) + (2 * tiny_dimension))) {
					union() {
						hull() {
							union() {
								peri_line_scad([-0.31904000514745706, -2.6799599948525428],[(-0.31904000514745706 + (((0.9600000000000006 + Effective_Shell_Thickness_For_FP1_0) + Effective_Shell_Gap_For_FP1_0) * -1.0)), (-2.6799599948525428 + (((0.9600000000000006 + Effective_Shell_Thickness_For_FP1_0) + Effective_Shell_Gap_For_FP1_0) * 0.0))],0.4);
								peri_line_scad([-0.31904000514745706, -20.18004102706909],[(-0.31904000514745706 + (((0.9600000000000006 + Effective_Shell_Thickness_For_FP1_0) + Effective_Shell_Gap_For_FP1_0) * -1.0)), (-20.18004102706909 + (((0.9600000000000006 + Effective_Shell_Thickness_For_FP1_0) + Effective_Shell_Gap_For_FP1_0) * 0.0))],0.4);
							}
						}
						hull() {
							union() {
								peri_line_scad([0.31904000514745706, -20.18004102706909],[(0.31904000514745706 + (((0.9600000000000006 + Effective_Shell_Thickness_For_FP1_0) + Effective_Shell_Gap_For_FP1_0) * 1.0)), (-20.18004102706909 + (((0.9600000000000006 + Effective_Shell_Thickness_For_FP1_0) + Effective_Shell_Gap_For_FP1_0) * 0.0))],0.4);
								peri_line_scad([0.31904000514745706, -2.679959994852542],[(0.31904000514745706 + (((0.9600000000000006 + Effective_Shell_Thickness_For_FP1_0) + Effective_Shell_Gap_For_FP1_0) * 1.0)), (-2.679959994852542 + (((0.9600000000000006 + Effective_Shell_Thickness_For_FP1_0) + Effective_Shell_Gap_For_FP1_0) * 0.0))],0.4);
							}
						}
					}
				}
			}
		}
		translate(v = [0, 0, ((PCB_Thickness - tiny_dimension) + max(-2.9997399854660034, Effective_Shell_Clearance_From_PCB_For_FP1_0))]) {
			rotate(a = [0, 0, 0]) {
				linear_extrude(height = ((min(((topmost_z + c_Base_Thickness) - c_Base_Line_Height), 2.54) - max(-2.9997399854660034, Effective_Shell_Clearance_From_PCB_For_FP1_0)) + (2 * tiny_dimension))) {
					union() {
						peri_line_scad([1.2690761200968321, -23.875616348529373],[1.4538521007304213, -23.95215285603328],0.4);
						hull() {
							union() {
								peri_line_scad([1.2690761204674887, 1.0156173317072148],[1.4538520269697461, 1.0921540181802327],0.4);
								peri_line_scad([1.0156173317072148, 1.2690761204674887],[1.0921540181802327, 1.4538520269697461],0.4);
							}
						}
						peri_line_scad([1.0156173317072148, 1.2690761204674887],[1.0921540181802327, 1.4538520269697461],0.4);
						hull() {
							union() {
								peri_line_scad([-1.0156173317072148, 1.2690761204674887],[-1.0921540181802327, 1.4538520269697461],0.4);
								peri_line_scad([-1.2690761204674887, 1.0156173317072148],[-1.4538520269697461, 1.0921540181802327],0.4);
							}
						}
						peri_line_scad([-1.2690761204674887, 1.0156173317072148],[-1.4538520269697461, 1.0921540181802327],0.4);
						hull() {
							union() {
								peri_line_scad([-1.2690761200968321, -23.875616348529373],[-1.4538521007304213, -23.95215285603328],0.4);
								peri_line_scad([-1.0156173308123695, -24.129076120838146],[-1.0921541962544274, -24.3138519532089],0.4);
							}
						}
						peri_line_scad([-1.0156173308123695, -24.129076120838146],[-1.0921541962544274, -24.3138519532089],0.4);
						hull() {
							union() {
								peri_line_scad([1.0156173308123695, -24.129076120838146],[1.0921541962544274, -24.3138519532089],0.4);
								peri_line_scad([1.2690761200968321, -23.875616348529373],[1.4538521007304213, -23.95215285603328],0.4);
							}
						}
					}
				}
			}
		}
		translate(v = [0, 0, (PCB_Thickness - tiny_dimension)]) {
			rotate(a = [0, 0, 0]) {
				linear_extrude(height = (min(((topmost_z + c_Base_Thickness) - c_Base_Line_Height), 2.54) + (2 * tiny_dimension))) {
					union() {
						hull() {
							union() {
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

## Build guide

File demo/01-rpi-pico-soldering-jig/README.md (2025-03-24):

# Soldering Jig for RPi Pico/Pico 2

Raspberry Pi Pico is available in with and without header variants. The price
difference between these variants is significant, typically around 1 USD.
Another way to look at it, it's 25% more expensive to buy the boards with
headers soldered!

Low cost headers are generally at a fraction of that price. Typically you get
40 pin headers that need to be broken into two and soldered. To solder the
headers you need to keep them straight. A breadboard may be used for this.

Using jigit, you can generate a 3D model for a soldering jig that you can 3D
print and use in many ways.

test-boards/footprint-test/README.md has an example that you can use to solder
without creating a complete jig. However, generating a dedicated jig has some
advantages. This is suitable, especially if:

* You want to try out this system
* You need to solder a lot of boards, and you want to make it as good and as
  painless as possible!
* You are a perfectionist who wants to (with proof!) solder perfectly vertical
  headers :smiley:
* You are running a training or learning program where attendees have to solder
  and achieve good results without needing high skill.

To generate the soldering jig, we need a model of Raspberry Pi Pico. Raspberry
Pi does not provide KiCAD files for Pico variants. Luckily, there a couple of
clone boards that we can use.  While not 100% clones, they are roughly boards
of the same dimensions as the Pico. They use the same positioning of the berg
headers. For the purpose of generating jig for soldering headers, they are useful!

Pre-generated jigs are included for easy usage in the jigs sub-directory. The
rest of this document explains how they were created.

## Project piCo

[Project piCo](https://github.com/sabogalc/project-piCo) has a few Pico clone
designs that include a USB-C connector, rather than the micro-USB connector
on the official board. Let's start by downloading these:

    git clone https://github.com/sabogalc/project-piCo.git

(NOTE: This was tested with commit 69bf9b9 of project-piCo git tree)

The file project-piCo/KiCad Projects/Pico C/RPI-PICO-R3a-PUBLIC.kicad_pcb is
a good start for jig creation. J1 and J2 are the single row 20 pin headers on
the board.  These are marked as "Front" mounted, though they are actually
mounted on the back of the board. This necessiates some tweaks.

project-piCo.toml has the settings required.  Creating the jig is a simple matter
of executing the following command:

    jigit \
        --bottom-components \
        -i project-piCo/KiCad\ Projects/Pico\ C/RPI-PICO-R3a-PUBLIC.kicad_pcb \
        -c project-piCo.toml \
        -o jigs/pico-soldering-jig.3mf

And then printing it ! This is how you will use the 3D printed jig:



Don't be surprised that the main PCB above doesn't look like a Rasperry Pi
Pico ! piCo is a clone with USB-C connector, with a slightly longer
PCB. That doesn't impact the long headers that we are interested in.
With FreeCAD, you may also checkout the fitting in the file
[fitting/project-piCo-with-soldering-jig.FCStd](fitting/project-piCo-with-soldering-jig.FCStd).

The printed jig works very well with a real Pico(2). It clearly reveals the
perfect fitment of the connectors at a glance, as you can see below:

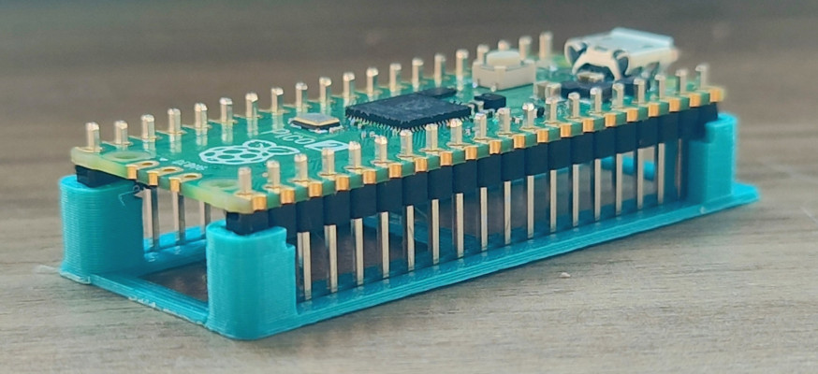
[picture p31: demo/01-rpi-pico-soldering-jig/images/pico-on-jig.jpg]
Jig from piCo


The jig is also efficient - consuming less than 2 grams of filament, and
printing in less than 15 minutes on my Prusa i3 MK2 at 0.2 mm layer height
with a 0.4mm nozzle. . For comparison, with the same settings on my printer
(these may change for you):

* [this jig on Printables](https://www.printables.com/model/739038-pico-soldering-jig) consumes
  8 grams of filament, with an estimated print time of about an hour
* Jig mentioned in this [Toms Hardware article](https://www.tomshardware.com/news/maker-creates-raspberry-pi-pico-3d-printed-soldering-jig)
  is less than 7 grams, with an estimated prints time of about half an hour

The settings in project-piCo.toml setup jigit to treat J1 and J2 as components
mounted on the bottom side (flip_side=false). You may tweak the other paramaters
to get various results:

* tweak line_width and line_height to make the jig chunkier
* increase thickness value in holder.base to create a frame that can
  be held in a PCB vice

## The Perfect Jig ?

What if you want to solder a 3 pin berg header as a debug connector ? Project
piCo does not include this.  Another clone, 
[Mitayi Pico](https://github.com/CIRCUITSTATE/Mitayi-Pico-RP2040) models it in
the right place.  However, it uses a right angled connector, which is frankly
not a problem, but that's not what I want to show here.

To help with this, I've created a simplified PCB design :
pico-th-jig/pico-th-jig.kicad_pcb . This models the external outline and
connectors on the board (including the debug header), but none of the actual
layout. For simplicity, headers are placed on the top side of the board.
To build a jig with this, use the corresponding config file pico-th-jig.toml,
as follows:

    jigit \
        -i pico-th-jig/pico-th-jig.kicad_pcb \
        -c pico-th-jig.toml \
        -o jigs/pico-all-soldering-jig.3mf

This jig lets you solder the 3 pin connector on either side of
the Pico. To mount the debug connector on the top side, solder it in first,
with the PCB facing down. Then reverse the PCB and solder the two 20
pin headers. The component shells are of the "tight" type (holes for every pin!),
which provides the best fit and the least chance of movement of component in
its place, at the cost of increased print time and material.

This jig prints in about 50 minutes, consuming about 6 grams of filament.

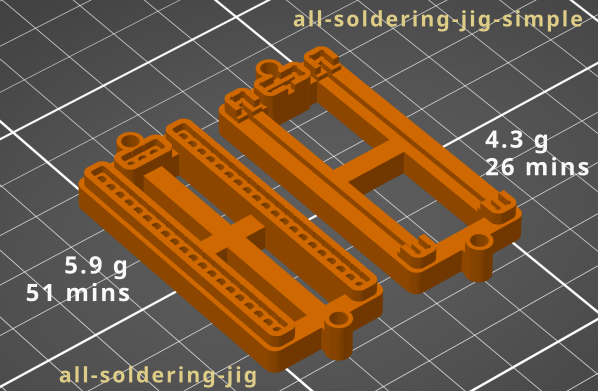
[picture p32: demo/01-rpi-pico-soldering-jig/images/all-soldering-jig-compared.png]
Comparison of soldering jigs


If you need a slightly simpler model that prints easier, faster and consumes
less material, then you can set the shell type to "fitting". This results
in a simpler model. Use this command:

    jigit \
        -i pico-th-jig/pico-th-jig.kicad_pcb \
        -c pico-th-jig-simple.toml \
        -o jigs/pico-all-soldering-jig-simple.3mf

This jig also has a provision to hold the PCB securely on the board using
a couple of M3 bolts and nuts. Perhaps this last part is a bit of
over-engineering, but this shows that if you need it, you can have it!

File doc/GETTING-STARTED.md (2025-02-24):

# Getting Started

Jigit directly works on KiCAD board files. It is an external tool.

Given a KiCAD board file, it generates a 3D model for a jig that keeps
components in place.  Once you 3D print the jig, you can use it to solder
components on the board with perfect results.  It also has experimental
support for holding SMD components in place without soldering
(check the demo directory).

For through hole components, jigit can handle cases with components of various
heights on the same board.

## Dependencies

Jigit has a few dependencies, you need to install them first:

- KiCAD (tested version 8). This installs kicad python modules also to python.
- OpenSCAD (recommended to use a development version with Manifold mesh support for fast mesh output)
- FreeCAD

Jigit is developed in python, and depends on the following modules

- toml
- shapely
- rectpack
- python_tsp
- trimesh
- pymeshlab

If you face package clashes, consider using python virtual environment to run jigit.

## Installation

Clone the jigit git repository to a location of your choice. If you intend to
use it frequently, set the PATH to include the location of the repository.

## Basic Usage

Jigit ships with some test files. These can be used to understand basic usage
and the fundamental concepts of Jigit.

test-boards/hello is a minimal hypothetical example - it's a board with a single
mounting hole and a 2 pin berg header.  To generate a jig for this, run:

$ /path/to/jigit /path/to-/jigit/test-boards/hello/hello.kicad_pcb -o hello.stl

This generates hello.stl.  You may also generate 3MF(.3mf) files, as well as
openscad (.scad) files.

When loaded into the slicer (image below from Prusa Slicer), you will be able to
see the details.  For this particular model, the jig has a single shell(cavity)
to hold the 2 pin berg header. There is a "lip" in which the PCB can sit.  The cylindrical hole can be used to push in an M3 screw to hold the PCB in place
with a nut on the other side.  The resulting model should print without any
failures, as it follows all the rules of design for FDM printing.

## Checking Generated Models

You can check the generated models by overlaying the generated models over 3D
models of boards.

FreeCAD can be used to check the generated models, as follows:

- Export a STEP file from KiCAD, taking care to select "Grid Origin" for coordinates.
- Import STEP file into FreeCAD. This will show the PCB and components. 
- Import STL file generated with jigit (export with --keep-orientation so that both share the same coordinate system)

Show/hide components/PCB/jig to check alignment.

## PCB Shapes

Jigit is designed to handle various PCB shapes, including circular and
arbitrary shapes.  Test boards hello-circle and "pacman" can be used
as examples.

## Tweaking Parameters

Jigit ships with reasonable defaults for common use cases. If you want
to improve the fitting of the components, you may need to create a configuration
file with parameters.  Jigit configuration files are in TOML. You may use the
--genconfig option to generate a configuration file.

An alternate way is to generate an openscad model using jigit. This lets you
tweak various parameters interactively with OpenSCAD's GUI.  Note that Jigit
internally creates and openscad file and exports 3MF or STL as requested.

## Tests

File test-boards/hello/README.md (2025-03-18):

This directory contains a minimal "hello" example.  It's a PCB with a single
2 pin berg header (one on each side of the board) and an M3 mounting hole.

The "gen" subdirectory contains example outputs from various commands, ready to
use with your slicer, FreeCAD and OpenSCAD. This can be used for demonstration
and learning.  There is no need to install JigIt to try these out - you only
need the tools that open the relevant files.

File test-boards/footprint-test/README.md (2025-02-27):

This directory has examples of how jigit can be used to generate shells directly
from components - i.e. KiCAD footprints.  KiCAD footprints typically have 3D models
associated with them. Jigit can use this information to generate holders for those
components. These holders may even be used standalone.

The common 2 Pin Berg header can be found in the KiCAD footprint library
"Connector_PinHeader_2.54mm" with the name "PinHeader_1x02_P2.54mm_Vertical". You can
directly pass this name to jigit and get it to generate models !

    jigit -c config.toml \
          --footprint Connector_PinHeader_2.54mm:PinHeader_1x02_P2.54mm_Vertical \
          -o 2pin_berg_header.scad

A footprint specifier consists of the library name and the footprint name, with a
colon (:) in between.

You may include multiple copies of a component in the output. This is useful to
generate models with different parameters (tolerances, shapes) and test them at
once.  The following command generates a 2x2 grid of 4 of these components:

    jigit \
      -c config.toml \
      --footprint Connector_PinHeader_2.54mm:PinHeader_1x02_P2.54mm_Vertical{4} \
      --arrange grid \
      --grid 2,2 \
      -o 4x2pin_berg_header.scad

config.toml defines the size of the print bed.  This is used to lay out models.
When laying out in a grid, models may be laid out using the "arrange" parameter
in various ways:

- in X followed by Y ("grid" or "grid_xy")
- in Y followed by X ("grid_yx")

Apart from a grid, models may laid out to fill the bed in specific directions:

- Arrange in X dimension first ("x")
- Arrange in Y dimension first ("y")
- Packed optimally ("xy")

Glob patterns work as well. The following command includes all the single row
vertical 2.54 mm headers upto 9 pins:

    jigit \
      -c config.toml \
      --footprint Connector_PinHeader_2.54mm:PinHeader_1x0*_P2.54mm_Vertical \
      -o kicad_single_row_headers.scad

To generate standalone components holders, they need a base. Let's generate two
pin headers suitable for soldering a Raspberry Pi Pico.

    jigit \
      -c config.toml \
      --footprint Connector_PinHeader_2.54mm:PinHeader_1x20_P2.54mm_Vertical{2} \
      --arrange grid --grid 2,1 -o 2x20pin_berg_header.scad

Open the output scad file next and set the following properties for both FP1 and
FP2:

- Wrapper Thickness to 3.0
- Wrapper Height to 1.0

This will give the holders a nice base. Try it out! Check 2x20pin_berg_header.stl
for a pre-generated ready to use model. If you need a thicker base, just increase
the height.

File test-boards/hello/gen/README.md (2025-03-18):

This directory contains pre-generated outputs corresponding to the test design
hello.kicad-pcb.  All the commands shown below are run from the root of the
source code base, thus they contain relative paths.

hello-kicad.step is an export of the PCB file from KiCAD, with the "Coordinates"
value set to "Grid Origin".

hello-jig.stl is a jig generated with default parameters (and in 3D printing
orientation), with the following command:

    jigit -i test-boards/hello/hello.kicad_pcb -o test-boards/hello/gen/hello-jig.stl

hello-jig-step-coord.stl is the same jig, but it is in the same coordinate system
as hello-kicad.step. It is generated as follows:

    jigit --keep-orientation -i test-boards/hello/hello.kicad_pcb -o test-boards/hello/gen/hello-jig-step-coord.stl

Note that the jigs holds components on the top side of the PCB. You may also create
a jig to hold components on the bottom side of the PCB, using the
--bottom-components option:

    jigit --keep-orientation --bottom-components -i test-boards/hello/hello.kicad_pcb -o test-boards/hello/gen/hello-jig-bottom-step-coord.scad

hello-jig-on-board.FCStd is a freecad file that includes hello-kicad.step and
hello-jig-step-coord.stl and hello-jig-bottom-step-coord.stl in the same file.
This allows you to understand the relative positioning among the various
elements with a user interface.

hello-jig.scad is the configuratble OpenSCAD output generated by jigit, using
the following command:

    jigit -i test-boards/hello/hello.kicad_pcb -o test-boards/hello/gen/hello-jig.scad

hello-jig.scad can be opened in OpenSCAD.  With OpenSCAD, you you can tweak
the model parameters interactively, generate 3D models, print and iterate.

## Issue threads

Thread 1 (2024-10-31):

Export STEP file

shreekumar3d, 2024-10-31:
jigify exports scad and stl files. stl is generated using openscad internally.  The intermediate internal output is scad format.

If a user wants to import the model to a CAD application (say FreeCAD), what can they do ? They can export from OpenSCAD into the CSG format. And then import that into FreeCAD. I have had mixed results with this. Depending on the model, it takes very long, even when it works. Internally freecad seems to be launching openscad anyways.  And all this is ultimately a very roundabout way of implementing this.

Jigify is internally building stuff from booleans. Generating STEP files as first class output will enable new category of use cases, as users can directly reference existing models rather than treat it as a mesh and then struggle with mapping faces etc.

This could be implemented in two steps:

1. Add initial support for STEP export, while still exporting curves as meshes. Curves are currently only in board outlines. We also convert 3D models such as step files to meshes.  This itself will be good for majority of use cases.
2. Handle curves natively. With this, we can handle curves. And if 3d models are STEP, we can pass them in directly, Kicad has uses VRML for rendering, but it has equivalent step files.  We can have an option to use STEP files preferentially.

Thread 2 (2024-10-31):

Create jigs directly from STEP files/meshes

shreekumar3d, 2024-10-31:
jigify works with KiCAD PCB files. This gives us a a lot of information about the board, which we leverage to make it easy to create a jig, in the following ways:

1. Footprints map to 3D models. We look at those models, their orientation and location relative to the PCB and then generate shells.  Component references include information about which side of the PCB the parts are mounted on.
2. Footprints also provide courtyards, which provides an easy fallback if nothing else is available
3. PCB board edge is extracted out of the PCB file from the Edge Cuts layer.

A KiCAD PCB may not always be available, and even in this case we want to have a way to generate a jig.  The user might be

1.  using a proprietary application to design the PCB. In this case, since the file format is closed, we may be unable to get the information
2. User might have got a step file from _somewhere_ and need to deal with it.
3. Nothing is available to the user except boards.  The user (perhaps an expert!) soldered it perfectly. 3D scans the PCBA. Gets a mesh out of it and now says - can you make me a jig !? (Sounds fanciful, but is it unlikely that this will ever happen ?)

In the conversion to a step file, all the board information is lost. A 3D scanned mesh or a mesh converted from a step file loses the idea of solids as well, but in some ways its a useful denominator to consider.  Supplementary information may or may not be available - e.g. gerber to get a board outline and any other information we can find useful.

A small amount of user assistance may be needed to pull this off. But this will be very useful.

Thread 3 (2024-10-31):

Create libraries of ready to use footprint shells

shreekumar3d, 2024-10-31:
KiCAD ships with footprints and 3d packages for a wide variety of components. These will be heavily used by users.

The option --footprint allows users to do this directly, but using this will need users to

- download and install jigify and its dependencies.
- understand the system to some extent
-- create a configuration file
-- install openscad

For any given user, the kind of components they are likely to use can be visualized as a palette, with the widely used colors coming from the in-built components (that's part of the reason why KiCAD has those models in the first place!). The fastest way to start is thus showing them the colors !

In other words - do the following

1. Create an automatic way to scan kicad libraries and components
2. Generate well ordered "sets". These could be the same sets, or subsets of what KiCAD provides. E.g. Connector_PinHeader_2.54mm has Horizontal TH, Vertical TH, Vertical SMD and Vertical SMD speciality parts. These are logically better placed in separate libraries. When we do that, the library sizes also become manageable. Horizontal TH and Vertical TH will have 80 components each, Vertical SMD will have 40 components, and Vertical SMD speciality will have 78 components
3. Upload these sets in OpenSCAD format - maybe in thingiverse as it supports customizer ? It might help to make smaller sets by number of pins as well.

In all cases, the derived datasets need to be distributed under CC-BY-SA-4.0 with attribution, as specified in kicad 3d models LICENSE file.

Making these available this way can benefit many more users. Users can then use these for quick fitting tests, tweak one scad variable and test out the 3d model. Then build the entire jig with the right tolerance. They can of course hack their way out of other situations by using these models as well.

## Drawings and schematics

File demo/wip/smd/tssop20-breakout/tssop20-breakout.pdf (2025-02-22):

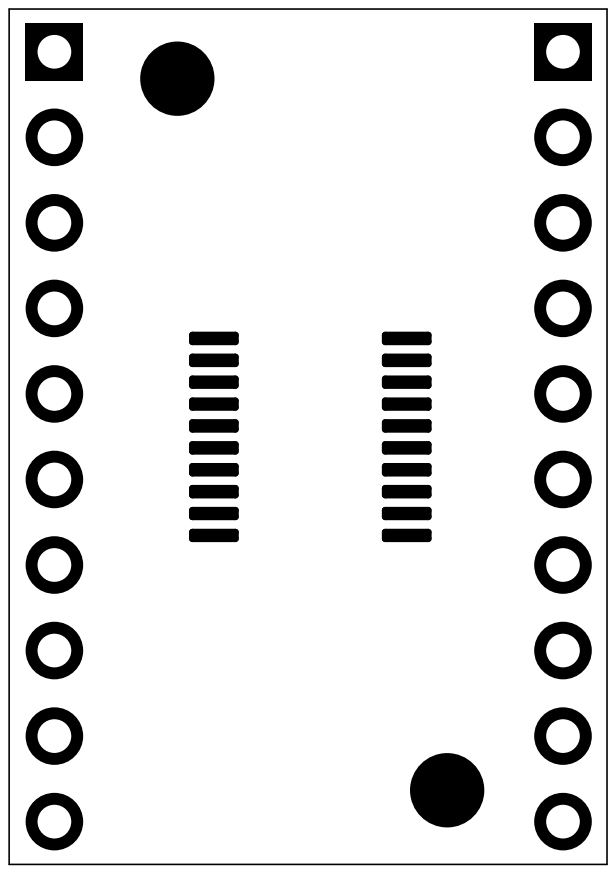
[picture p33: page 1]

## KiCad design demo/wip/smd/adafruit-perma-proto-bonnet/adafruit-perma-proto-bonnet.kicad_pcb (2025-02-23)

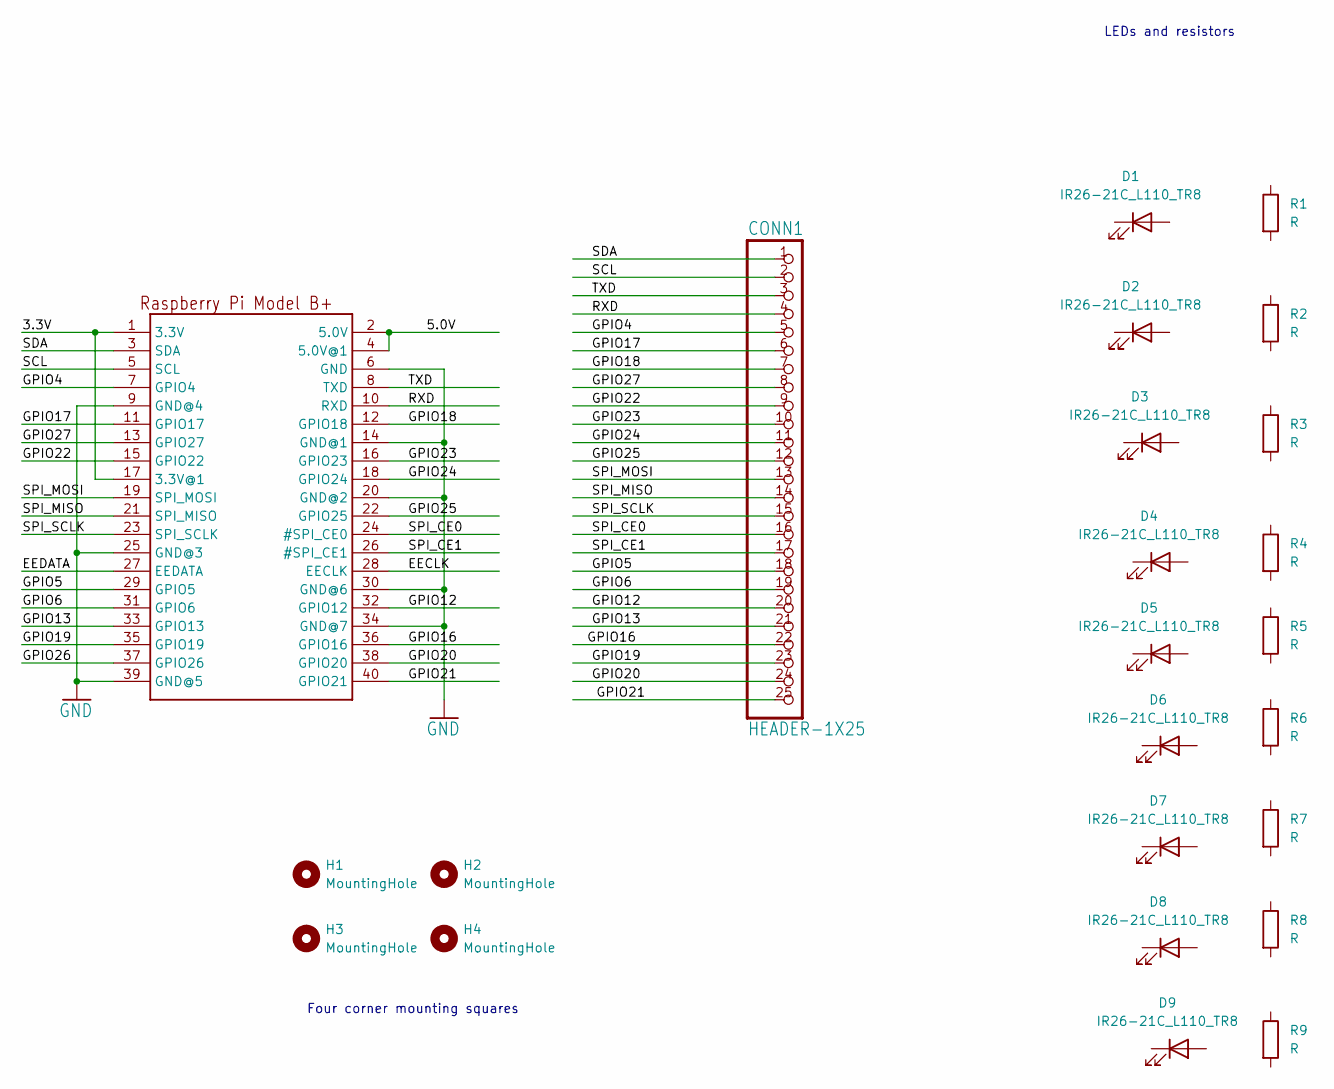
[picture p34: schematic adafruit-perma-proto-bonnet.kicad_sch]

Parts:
CONN1: HEADER-1X25; 1X25_ROUND_70MIL
D1, D2, D3, D4, D5, D6, D7, D8, D9: IR26-21C_L110_TR8; LED_1206_3216Metric
H1, H2, H3, H4: MountingHole; MountingHole_2.7mm_M2.5
R1, R2, R3, R4, R5, R6, R7, R8, R9: R; R_1206_3216Metric
RPI1: RASPBERRYPI_BPLUS_BONNETNODIM; PI_BONNET_NODIM

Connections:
/3.3V: RPI1.1 (3.3V), RPI1.17 (3.3V@1)
/5.0V: RPI1.2 (5.0V), RPI1.4 (5.0V@1)
/EECLK: RPI1.28 (EECLK)
/EEDATA: RPI1.27 (EEDATA)
/GPIO4: CONN1.5, RPI1.7 (GPIO4)
/GPIO5: CONN1.18, RPI1.29 (GPIO5)
/GPIO6: CONN1.19, RPI1.31 (GPIO6)
/GPIO12: CONN1.20, RPI1.32 (GPIO12)
/GPIO13: CONN1.21, RPI1.33 (GPIO13)
/GPIO16: CONN1.22, RPI1.36 (GPIO16)
/GPIO17: CONN1.6, RPI1.11 (GPIO17)
/GPIO18: CONN1.7, RPI1.12 (GPIO18)
/GPIO19: CONN1.23, RPI1.35 (GPIO19)
/GPIO20: CONN1.24, RPI1.38 (GPIO20)
/GPIO21: CONN1.25, RPI1.40 (GPIO21)
/GPIO22: CONN1.9, RPI1.15 (GPIO22)
/GPIO23: CONN1.10, RPI1.16 (GPIO23)
/GPIO24: CONN1.11, RPI1.18 (GPIO24)
/GPIO25: CONN1.12, RPI1.22 (GPIO25)
/GPIO26: RPI1.37 (GPIO26)
/GPIO27: CONN1.8, RPI1.13 (GPIO27)
/RXD: CONN1.4, RPI1.10 (RXD)
/SCL: CONN1.2, RPI1.5 (SCL)
/SDA: CONN1.1, RPI1.3 (SDA)
/SPI_CE0: CONN1.16, RPI1.24 (#SPI_CE0)
/SPI_CE1: CONN1.17, RPI1.26 (#SPI_CE1)
/SPI_MISO: CONN1.14, RPI1.21 (SPI_MISO)
/SPI_MOSI: CONN1.13, RPI1.19 (SPI_MOSI)
/SPI_SCLK: CONN1.15, RPI1.23 (SPI_SCLK)
/TXD: CONN1.3, RPI1.8 (TXD)
GND: RPI1.6 (GND), RPI1.9 (GND@4), RPI1.14 (GND@1), RPI1.20 (GND@2), RPI1.25 (GND@3), RPI1.30 (GND@6), RPI1.34 (GND@7), RPI1.39 (GND@5)

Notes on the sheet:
Four corner mounting squares
LEDs and resistors

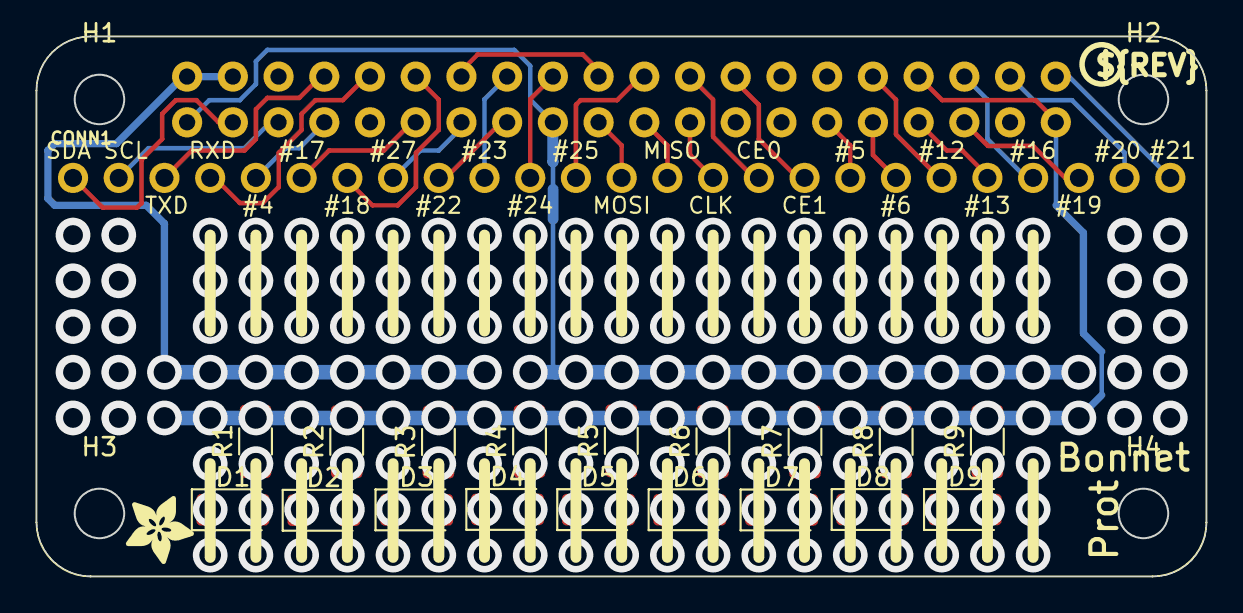
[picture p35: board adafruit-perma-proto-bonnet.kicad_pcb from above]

Board: 2 copper layers, 65.0 x 30.0 mm, 26 parts (0 on the bottom side), 28 nets.

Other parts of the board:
U1: ADAFRUIT_3.5MM
U3: PCBFEAT-REV-056

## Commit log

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2024-10-23 courtyard shell, param tuning in oscad customizer
    Courtyard shell type is implemented. It is now possible to tweak all
    component parameters in OpenSCAD customizer at a per-component level:
    - insertion direction
    - shell thickness
    - shell gap
    - shell clearance from PCB
    - include/exclude in model
    There could be lots of refs on a board. Largest refs (by courtyard area)
    are shown first in the customizer so that it's easier to find them.
    This is quite nice, but it also means that the global values no longer
    work. How do we deal with this ? Customizer does not allow cross
    dependency between parameters. So, to propagate values consistentyly,
    we can at best aim to make it additive. This needs to b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
2024-10-23 Beautified preview in oscad,with show/hide options
    PCB, component holders and SMD keepout volumes can be independently
    visualized. These are clearly shown in different colors. It's not
    perfect, but it's pretty good!
    oscad background operator % is used as it allows color control, without
    adding to output geometry. The debug modifier # has a fixed color, so
    not used.
    PCB is centered around the origin now to aid 3D interaction.
    This is not applied if --keep-orientation is used.
    Base can be switched between mesh/solid.
2024-10-23 Support Jig Type in customizer
    There are limits to this currently - e.g. delaunay mesh isn't
    computed in OpenSCAD. So, it has limited use.
2024-10-24 Pythonic extraction of courtyard points.
    Courtesy user q1ck on kicad forums,
    https://github.com/openscopeproject/InteractiveHtmlBom/blob/5915a249b14bd91986c6062b551b18dc9de394e0/InteractiveHtmlBom/ecad/kicad.py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
2024-10-25 Per component settings deltas, inherited from FP.
    Much cleaner UI also now. Settings feel logical.
    Global settings now correspond to SMD components.
    Footprint wise settings can be configured, and
    overridden on a per component level with deltas.
2024-10-25 New "griddish" base type
    This is a grid that includes all the footprint center. Basically,
    it draws an X and a Y line on the base, for every footprint included
    in the output.
    This gives it a grid like appearance. The lines also likely pass
    through the shell X & Y axis.
    Delaunay can cause strange print moves, but look cool, depending on
    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
2024-10-27 Hack-in-progress: tight shells
    convex hulls works quite well for things like berg headers to generate
    "fitting" shells. But I want to generate concave shells for concave
    parts - so that the cavity follows the model better. how to make that
    happen ?
    The ideal solution can be visualized as - offset the solid 3D model,
    sweep it out along negative Z. This gives the subtraction volume, or
    the holder for the component.
    In this hack, I've used a modified z walk, based on the shell-zbins.
    It works pretty well for something like a berg header - showing its
    external outline perfectly. So far so good, but it crawls for complex
    meshes with curved surfaces. Commit to save this work.
    If you run this,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
2024-10-27 Discrete steps for better performance
    Fixed bug where triangles were being skipped. With 0.2mm
    z step I get reasonable, but not perfect results.
    Some artifacts are visible in the final shape - like gaps -
    almost as if something is slipping between the cracks.
2024-10-27 Fill small holes, output 1 shape
    Holes are filled using a small offset. Post that, if we have multiple
    shapes, we carefully union them triangle by triangle. After this,
    we reverse the offset. This then becomes the final output.
2024-10-27 Hack tightbin: Export final plane as STL.
    Had an aha moment after this - when I visualized the output in
    3D. Some of the polygons coming in the output are holes. That's
    why they refused to go away!
2024-10-27 tight shell:Reject holes,instead of processing em
2024-10-29 Expand small areas to a configurable limit
    Very small holes (e.g. berg header pins) can't be printed by FDM
    printers. This presents a problem for tight shells.
    One way out is to offset small areas till they are large enough.
    We do that iteratively here. No more than 1mm of offset would be
    required, so a limited search is enough.
    For users who might have resin based printers, smaller offsets
    would suffice. This is controllable via the new config parameter
    3dprinter.min_printable_hole_area
2024-10-29 Hack: fix issues in inner corners of fitting bins
    Inner corners of fitting bins are created by subtracting volumes.
    These serve as nice pockets, but also create new 3D printing challenges.
    3D printers round off corners - this causes fitting issues.
    A decent fix is avoiding tight corners. This hack demonstrates this
    in action. Basically, for every vertex in the polygon of the cutting
    volumes, we add a circle the size of an FDM nozzle. This eliminates
    the corner. Crucially, it keeps the corner clear of filament -
    thus resulting in a good fit.
    This also cuts into the outer shell, increasing the number of print
    moves and also weakening it. Thus, 1.2 mm (3 nozzles) is the minimum
    recommended s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
2024-10-30 Corner avoidance now respects shell thickness
    Earlier, corner avoidance would cut into the external shell.
    Now, all the inner corners are accumulated and unioned with
    the external shape.
    Due to this, we can get back to 0.8 mm (2x nozzle) shell thickness.
    Also this improves print moves due to the continuity on the outer
    shell.
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2024-10-31 Default shell type is now 'fitting'
    This is robust enough and better results than wiggle. Also, since
    the footprint grouping change, it is no longer possible to change
    all shells in one click. This looks right. If fitting does not
    work for somebody, then they can always fall back to wiggle, or
    even courtyard.
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2024-11-02 Corner avoidance with cuts for fitting shells
    Corners were being cut earlier with circles. This created issues as it
    created variances in the shell width.
    The change goes one better - we radially cut at corners - all the way to the
    end of the shell. This saves material as well. In the Z axis, the cuts
    stretch all along the Z span of each bin. This creates a very tiny
    bridge for the next bin, but its so small that it won't be an issue.
    Note that the cut volumes created by this corner avoidance cut through
    all the shells. This is necessary as shells can potentially intrude into
    other shells due to the thickness of their walls.
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2024-11-02 x_lines and y_lines are now connected to frame
    Without that, components can hang in the XY plane. With
    corner cuts they can hang even otherwise.
    Also fixes y negation bug in y_lines
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2024-11-04 Fix: honour ref_shell_clearance on fitting flowers
2024-11-04 Fix:flower shell must have a solid base if short
    Problem was observed at the USB connector - it is not a tall
    component - and there was a well for it to fall. Fix is to
    make an extra solid that includes the base all the way till the
    max z of the ref
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2024-11-04 Initial implementation : Mounting hole spacer jig
    Saves 50% material and 50% time compared to without, for the
    AtiVEGA board.
    Basically for a good height, the jig will just be printing
    vertical shells. This can be substituted by using 3d printed
    spacers. Base layer is still required. The spacer is the
    same shape as the mounting hole outlines.
    Limitations: one or more extra base layers (near to topmost_z)
    may need to be printed, if component ends around that place.
    Need to add a policy for this.
    Here, we use the first_layer_height as well. Shouldn't be a problem
    as in most cases it is fair to assume this will be 0.2 mm
    We also create shadow variables in scad. Basically this jig
    type ove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
2024-11-05 Option to add extra mounting holes
    Pass a list of [x,y,diameter] and mounting holes will be added at
    those locations. We should probably check that they are out of the
    PCB too. (Inside makes no sense, and could potentially create issues)
    Also, spacers will be added if creating such a jig.
    Also fixes a bug in previous commits, where the diameter of mounting
    holes was incorrectly computed.
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2024-11-05 Fix broken scad UI functionality
    Mesh lines work with mounting hole jig now
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2024-11-05 Now called jigit
    The Gaffer, he says:"Make it short, and then you won't have to cut
    it short before you can use it".
    jig-it I say! Let's make it as simple as possible, but not _simpler_
2024-11-05 Disable print included by mistake
2024-11-05 Simple test for component orientation
    [component-orientation-test.kicad_pcb, component-orientation-test.kicad_sch, ssd1306-xrot90.step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]
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2024-11-07 Handling of base and wrapper in standalone mode
    Footprints that have more than one 3d model (e.g. Pico, Mini360 etc)
    need extra handling for the base and wrappers. In "jig" mode,
    base is assumed, and things are supposed to be attached in some way
    to the base.
    In standalone mode, that doesn't happen. So the base/wrappers have
    to be generated additionally.
2024-11-07 Fix: working courtyard shells in non-pcb mode
    When "pure" footprints are loaded (i.e. without a PCB), somehow
    the courtyards aren't returned. Shells were empty due to this.
    I couldn't figure out from the KiCAD source code the exact reason.
    But I was able to figure out that the drawings are available. So
    I made my edge cuts code reusable and used that code to compute
    the courtyards. With this, courtyard shells now work!
2024-11-07 Fix: bad comparison disabled cut-through shell
    Cut through shells aren't pretty, but yet, let's keep it for now.
2024-11-07 Long petals be cut in the middle to save material
    Mostly saves time as well, so double win. Current
    approach may not work in ann cases, as noted in the
    code.
2024-11-08 Mesh lines cut by volumes make islands. Avoid that
    Cut volumes were earlier cutting into mesh lines. These are structures
    designed to ensure the output is one piece. This is bad of course, as
    it requires analysis of the result to figure out if something won't
    work. Of course, base_thickness>0 can help by eliminating islands, but
    that is potentially wasteful in terms of both material and time.
    This change ensures mesh lines won't be cut into. So the structure will
    remain one piece
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2024-11-21 Fix fatal logical flaw in hull_poly
    This commit must be seen with 5416318b9d951408e229cc211abffb19036e016a
2024-11-21 Avoid mesh lines, done right.
    Cut volumes were incorrectly shifted up. The proper approach is to
    clamp start_z to shell_clearance, and end_z to avoid mesh line.
    This change does that.
2025-02-22 TSSOP20 breakout board design.
    Reverse engineered from off-the-shelf component.
    See README.md for details.
    [scan-helper.3mf, scan-helper.FCStd, tssop20-breakout.kicad_pcb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]
2025-02-22 First cut support for SMD
    Generate SMD shells, if --enable-smd-shells is specified. SMD shells
    are generated in addition to TH shells. If this is undesirable, then
    the TH shells must be disabled using refs_do_not_process (see
    demo/tssop20-breakout/config.toml for example).
    Configuration properties for SMD shells mostly mirrors TH shells,
    except for some specific propoerties such as force_smd.
    There is a risk something may be broken. 4 different type of shells
    are supported, as with TH shells, so of these are useful for larger
    components, but maybe not so much for the tiny SMD components.
    Z bin size is hardcoded to 0.1, this is best implemented as a
    configuration parameter.
    Enabling SMD sh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
2025-02-22 Better alignment of chip footprint in breakout
    Chip is moved lower by 0.325 mm. Determined empirically by printing
    a jig. Last leg was between pads. So moved down by gap between pads
    plus half of extra width of the pad.
    [tssop20-breakout.kicad_pcb]
2025-02-23 Adafruit Perma Proto Bonnet, imported to KiCAD 8
    The source is in Eagle:
    https://github.com/adafruit/Adafruit-Perma-Proto-Bonnet-PCB
    This is imported to KiCAD 8. Need this to test SMD LEDs.
    [adafruit-perma-proto-bonnet.kicad_pcb, adafruit-perma-proto-bonnet.kicad_sch]
2025-02-23 Fix board outline on perma proto bonnet
    There was a DRC issue, and the board outline wasn't showing up
    properly in KiCAD. This was due to overlapping lines in the
    board outline.
    Either Eagle allows overlapped lines, or this is a KiCAD issue
    converting from Eagle to KiCAD.
    [adafruit-perma-proto-bonnet.kicad_pcb]
2025-02-23 Fix bad chars in footprint identifiers
    scad can't handle $ in symbol names. This will be a limitation of
    the tool
    [adafruit-perma-proto-bonnet.kicad_pcb]
2025-02-23 Add corner mounting holes on perma proto board
    [adafruit-perma-proto-bonnet.kicad_pcb, adafruit-perma-proto-bonnet.kicad_sch]
2025-02-23 Add test 1206 LED and Resistor in bonnet PCB
    [adafruit-perma-proto-bonnet.kicad_pcb, adafruit-perma-proto-bonnet.kicad_sch]
2025-02-23 feat:refs_do_not_process for SMD
    This property is useful for SMD as well to selectively include/
    exclude refs in the design (like TH).
    Filter out refs that are in this list. Useful, among other reasons,
    to deal with file format conversion/import issues (I am facing this
    with the adafruit perma proto bonnet, see config.toml in commit)
    Tested with:
    ./jigit \
    --enable-smd-shells \
    -i demo/adafruit-perma-proto-bonnet/adafruit-perma-proto-bonnet.kicad_pcb \
    -o demo/appb2.scad \
    -c demo/adafruit-perma-proto-bonnet/config.toml
2025-02-23 Fix:Ensure mounting hole shells press PCB
    If these stretch all the way till the PCB, there will be no
    press action on the components. Mounting hole shells must end a bit
    short (same as SMD clearance) so that a small amount of force keeps
    the components pressed. Note that this shouldn't be large - that
    will distort the holding jig. 0.2 - 0.5 mm should be fine.
2025-02-23 feat:"solid_fill" base type for SMD usage
    Wireframe-ish jigs like what we use with TH components do not
    help keep components in place with a small force.
    With this base type, the entire holding jig becomes solid apart from the
    cut volumes. This gives adequate stiffness to the holding jig.
2025-02-23 Populate demo board with 9 LEDs
    Location moved to lower row. Resistors are placed such that they
    connect to ground. Shell gap increased slightly so that LED can
    sit comfortably - probably will be loose for the resistor. Can
    be tuned further.
    [adafruit-perma-proto-bonnet.kicad_pcb, adafruit-perma-proto-bonnet.kicad_sch]
2025-02-24 kicad share dir in cfg,option to dump path issues
    KiCAD path isn't detected, we can't assume a fixed path like
    /usr/share/kicad like what we do in Linux. So this is now
    configurable
    Add a --show-paths option to help identify issues user might face.
    Ideally we'd detect if tools are actually on PATH and working, but
    this is a start.
2025-02-25 Add generated outputs for test-boards/hello
    README.md explains the commands and how to use the files. Should
    allow for easy tests without installing jigit itself.
    [hello-jig-on-board.FCStd, hello-jig-step-coord.stl, hello-jig.scad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]
2025-02-25 fix:get --footprint working again
    kicad config parameter had broken it.
2025-02-27 footprint-test to show "no board" usage
    [2pin_berg_header.scad, 2x10pin_berg_header.scad, 2x20pin_berg_header.scad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]
2025-03-18 Use build123d to load STEP files
    freecad was being used earlier to load STEP files. This had couple of
    downsides:
    - required FreeCAD installation as a prerequisite to use the tool
    - confusing failures. FreeCAD snap package on linux may fail loading
    step files due to lack of permission to access /usr/share/kicad
    Using build123d eliminates these issues.
2025-03-18 hello test board with components on both sides
    [hello-jig-on-board.FCStd, hello-jig-step-coord.stl, hello-jig.scad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]
2025-03-19 Better control in SCAD GUI for shell fine tuning
    Shell gap, thickness and clearance need to be configurable with
    proper granularity.
    Shell thickness can be technically as small as 1 nozzle (considering
    0.25mm nozzle). Gap can be in steps of 0.05 mm. Clearance granularity
    of 0.1 mm is enough.
2025-03-19 Feat:Support to flip side for TH components
    In stock KiCAD footprints, "front" mounted TH components are oriented
    such that the soldering happens on the back side of the PCB
    (i.e. reverse side).
    Boards by various developers don't seem to follow this convention.
    I have seen boards (e.g. https://github.com/sabogalc/project-piCo)
    that have front mounted berg headers oriented such that soldering
    is required on the front side.
    To handle such cases, I have introduced a "flip_side" property for
    TH components. This defaults to false. Setting this to true transforms
    the 3d shapes, moving them to the other side. With this change,
    such components can be handled. Thus, users don't need to change the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
2025-03-19 Moved SMD demos to demo/wip/smd
    Once values are well tuned, plan to move it to demo/smd
    [adafruit-perma-proto-bonnet.kicad_pcb, adafruit-perma-proto-bonnet.kicad_sch, scan-helper.3mf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]
2025-03-20 Documented RPi Pico Jig
    [pico-all-soldering-jig.3mf, pico-soldering-jig.3mf, pico-th-jig.kicad_pcb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]
2025-03-21 Added Pico Glitcher jig demo
    [pico-glitcher-jig.3mf, pico-glitcher-v1.1-with-jig.FCStd]
2025-03-21 Use FPID when footprint field is empty
    Found footprint field empty in mixolydian-4x4 board, but the footprint
    has the right 'Library Link'. So using that (FPID) as the footprint
    name.
    My boards seem to have both, and it's not clear which takes precedence.
    Tracking with a FIXME
2025-03-22 Pockets cut through PCB to avoid overhangs
    Sometimes components can straddle the edge of the PCB, or be very
    close to the edge. When pockets don't cut through the PCB,
    some plastic may hang in thin air near the edge. This change
    ensures that all pockets (courtyard, wiggle, fitting and tight)
    cut through the PCB. This is done by increasing the height of the cut
    volume by pcb thickness, and making it begin at z=0.
2025-03-24 "Clearance from PCB" is the right terminology
2025-03-24 Improved doc for RPi Pico jig
    [pico-all-soldering-jig-simple.3mf]
2025-03-24 Fix generation of groove all around PCB edge
2025-03-24 Add FOSSDEM Audio Board demo
    Shows off some of the interesting aspects of jigit, and benefits
    of benefits of the sparse structure as opposed to solid jigs.
    [mixolydian-4x4-jig-fitting.FCStd, mixolydian-4x4-soldering-jig-solid.3mf, mixolydian-4x4-soldering-jig.3mf]
2025-03-24 Number demos for ordering
    [mixolydian-4x4-jig-fitting.FCStd, mixolydian-4x4-soldering-jig-solid.3mf, mixolydian-4x4-soldering-jig.3mf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]
2025-03-25 Fix:smallest "tight" bin must start at max_z
    The existing code ignores max_z, if the mesh's lowest Z (max_z)
    is a single point, or a single edge. This happens as section
    returns empty. Regardless, the first bin must start at max_z.
    [mixolydian-4x4-jig-fitting.FCStd, mixolydian-4x4-soldering-jig.3mf]
2025-03-25 New 'wiggle_minus' shell type
    The existing wiggle shell is basically a convex hull, providing a
    loose fit.
    wiggle_minus is wiggle, operating on the potentially concave hull
    created by the "tight" algorithm. This should benefit both front
    and back insertion, as the component can be better constrainted
    in terms of orientation and movement.
2025-03-25 Couple of fixes
    Ensure footprints are shown in scad UI
    Define ranges in proper script, else script barfs
2025-03-25 Fix (regression) broken mounting hole support
2025-03-26 AtiVEGA demo
    Shows simple usage, openscad and 2 part jigs.
    [ativega-2part-jig.3mf, ativega-jig.3mf, ativega-jig.scad]
2025-03-26 Gridfinity Demo
    [base-gridfinity-1x1.stl, gridfinity-1x1.3mf, gridfinity-1x1.FCStd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]
2025-03-27 force_mount option to flexibly place shells in Z
    TH shell with min_z > 0 was taken to be not mounted. This was done
    to process mounted modules such as the Pico on Thejas32.
    force_mount ignores the min_z comparison and includes all models
    in the shell. Doing so changes the meaning of clearance_from_pcb.
    It now cuts from the top of the 3d model, if that has min_z > 0.
    This allows us to cut the top of the shell independent of the
    Z location, with a single parameter. If we didn't change this
    interpretation, multiple components of the same type, with different
    Z location would end up needing distinct values of clearance_from_pcb.
    With this in place, we can have many components laid out arbitrar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
2025-03-27 Gridfinity allen key holder demo
    Based on 2x1 gridfinity container
    [2-HexKey.step, 3-HexKey.step, 4-HexKey.step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]
2025-03-28 Improved corner segmentation
    Track cumulative difference in angle to segment corners. Instantaneous
    angle change does not work when finely segmented curves slowly change
    angle; this was causing such lines to be considered one.
    This commit also fixes a bug w.r.t omitting the first and last segmented
    lines.
2025-03-28 Update allen keys demo with cut tight shells
    [allen-key.FCStd, allen-keys.3mf, gridfinity-container-allen-keys.stl]
2025-03-28 Include missed check for skipping tight cut
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2025-04-02 Demo of ProtoConn with lots of connectors
    [ProtoConn-soldering-jig-fitting.FCStd, ProtoConn-soldering-jig.3mf]
2025-04-04 Fix failure when pcb file is in current directory
    For a file in the current directory, split returns empty as the
    directory path. Use '.' in that case
2025-04-04 Fix:set default display_name to kicad_footprint
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2025-04-04 Fix minor issues (see details)
    force_mount must set min_z to 0, else shell will not cut right
    through.
    default KIPROJMOD (no pcb) is '.', else footprints won't work
    from local directory.
    Corrected top side determination in footprints
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2025-04-08 Right use of SMD clearance_from_shells
    It's the extra cut that is needed in plastic, to deal with tolerance
    issues.
2025-04-11 solid base now works with trim below z
    solid is a base style, but it wasn't moving with the trim_below_z
    plane. This commit fixes this. Technically, this implements mesh
    lines that are solid.
    solid base uses the mounting hole frame as the shape for
    component_fitting jigs. For TH_soldering, the PCB edge is used.
    Couple of things to correct later (TODO):
    - solid_fill is not a base style technically; it's a jig style
    - MH frame or PCB should must be a policy
    - shell_style='support' must not overload shell_gap. Doing so
    complicates configuration file. Users need to maintain
    consistency across two or more config files.
2025-04-13 fix:handle frame without no mounting holes
    When there are no mounting holes, mounting hole frame will be
    empty. Handle this zero length case
2025-04-13 Clearance for mounting hole shells
    mounting holes shells are distinct compared to component shells.
    Depending on whether they are "in" or "out" of the PCB, they have
    different heights - stretching all the way till the PCB or till
    the top surface. Postive z values work like for component shells,
    negative values extend shells "up"
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2025-04-14 fix:don't create islands when MH are outside PCB
    Mounting holes can be outside base volume. Cutting the lines
    creates islands in such cases
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2025-07-03 fix: correct bottom side jig model orientation
    Turns out KiCAD effectively reverses X axis on 3D models for bottom.
    If we don't follow, our X is flipped for bottom side components.
    It's not clear if this is a "hack" or a "fix".
